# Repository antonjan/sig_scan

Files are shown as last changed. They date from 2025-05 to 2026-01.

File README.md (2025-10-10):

# sig_scan
This project will scan for rf signals and report them if there is signals detected using an rtl-sdr dongle on a a Raspberry Pi<br>
Libraery with exsyended frequency is avalable here https://github.com/librtlsdr/librtlsdr/tree/development<br>
## Pre Req libraeriies
    sudo apt-get install build-essential cmake git
    sudo apt-get install libusb-dev libusb-1.0-0-dev
    git clone https://github.com/librtlsdr/librtlsdr/tree/development
    cd librtlsdr
    git checkout development
    git status

    mkdir build && cd build
    cmake ../ -DINSTALL_UDEV_RULES=ON
    make

    sudo make install
    sudo ldconfig
# Setting up python 
    cd Documents/SX126X_LoRa_HAT_Code/raspberrypi/python/
## Sender 
    source ~/sdr-env/bin/activate
## Receiver
    source venv/bin/activate
# Running SIG Scanner
python gsm_scanner_new2.py

# Rafial R828D pin conections

    R828D (R820T-compatible) Pinout: Pin Number to Name

The R828D is usually supplied in a 32-pin QFN package. Here’s the most commonly reported pinout:

        Pin	Name	Function
        1	VCC	Power supply
        2	VCO	PLL VCO
        3	VCOIN	PLL VCO input
        4	VCOGND	PLL VCO ground
        5	VCOBUF	PLL VCO buffer output
        6	XIN	Crystal oscillator input
        7	XOUT	Crystal oscillator out
        8	VCC	Power supply
        9	GND	Ground
        10	AGC	Automatic Gain Control
        11	IFOUT	Intermediate Frequency Output
        12	VCC	Power supply
        13	GND	Ground
        14	RF_IN	RF Input (from antenna)
        15	GND	Ground
        16	NC	Not Connected
        17	VCC	Power supply
        18	NC	Not Connected
        19	LNA	Low Noise Amp control
        20	VCC	Power supply
        21	GND	Ground
        22	NC	Not Connected
        23	SDA	I²C Data
        24	SCL	I²C Clock
        25	GND	Ground
        26	VCC	Power supply
        27	NC	Not Connected
        28	VCC	Power supply
        29	NC	Not Connected
        30	NC	Not Connected
        31	NC	Not Connected
        32	NC	Not Connected
        30	NC	Not Connected
        31	NC	Not Connected
        32	NC	Not Connected
## Basic Connections

    Antenna → Matching Network → Pin 14 (RF_IN)
    Pin 11 (IFOUT) → RTL2832U IF Input
    Pin 23 (SDA) & Pin 24 (SCL) → RTL2832U I²C (for control)
    Pin 6 (XIN) & Pin 7 (XOUT) → 16 MHz Crystal (one end to XIN, other to XOUT, with load capacitors to GND)
    All VCC Pins → 3.3V Power
    All GND Pins → Ground Plane

## Register Map (Community Reference, RTL-SDR Driver)

The R828D is controlled via I²C. The register map is not openly published, but the rtl-sdr driver configures it as follows:

    I²C Address: 0x8C (write), 0x8D (read)
    Registers:
        Reg 0x00: Tuner enable, AGC, LNA setting
        Reg 0x01–0x05: PLL and frequency control
        Reg 0x06–0x0D: IF settings, filter bandwidth, gain stages
        Reg 0x0E–0x1F: Misc control, calibration, test modes

Example I²C Write Sequence for Initialization:
    
    uint8_t init_regs[] = {
    0x01, 0x16, 0xE0, 0x60, 0x40, // PLL settings
    0x20, 0x80, 0x40,             // IF gain, filter
    0xA1, 0x4B, 0x10              // AGC, LNA, etc.
    };
    i2c_write(R828D_ADDR, init_regs, sizeof(init_regs));
The actual values depend on frequency, IF, and gain requirements.
Refer to rtl-sdr tuner_r820t.c for full register programming examples. https://github.com/osmocom/rtl-sdr/blob/master/src/tuner_r820t.c

Step-by-Step Build Guide

    Connect RF_IN (Pin 14) to antenna/matching network.
    Connect IFOUT (Pin 11) to RTL2832U IF Input.
    Connect SDA (Pin 23) and SCL (Pin 24) to RTL2832U I²C bus. Use pull-up resistors (~4.7kΩ) to 3.3V.
    Connect 16 MHz crystal between XIN (Pin 6) and XOUT (Pin 7), with recommended load capacitors (~22pF) to ground.
    Connect all VCC pins to regulated 3.3V supply.
    Connect all GND pins to system ground.
    AGC (Pin 10) and LNA (Pin 19) can be controlled by RTL2832U or tied appropriately.
    Initialize R828D via I²C using register sequences from open-source drivers.
# R828 c driver 
https://github.com/osmocom/rtl-sdr/blob/master/src/tuner_r82xx.c

    Pin 10 (AGC) → RTL2832U AGC Output (optional, for gain control)
    Pin 19 (LNA) → Can be tied HIGH or controlled by RTL2832U for LNA operation

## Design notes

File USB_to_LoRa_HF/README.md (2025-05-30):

# USB to LoRa HF

The USB-TO-LoRa-xF is a wireless data transfer unit with USB interfaces based on the SX1262 module. Adopts LoRa Modulate and Demodulate technology, with the advantages of anti-interference and long-distance communication (up to 5KM). Supports point-to-point, point-to-multipoint, relay network, AES, etc. Compact size and easy to install.

## How to Restore from Brick

1. Use the Firmware update software on a Windows machine.
2. Put the device into firmware update mode by holding down the KEY button within 3 seconds of powering the device on. The TXD and RXD LED's will flash to show you are in the correct mode.
3. Open the Update software, select the correct COM port and press 'Open COM'.
4. Press on 'Open File' and choose the latest firmware for the corresponding model, such as USB-TO-LoRa-HF-V12.ws, and click the 'Update' button to update.

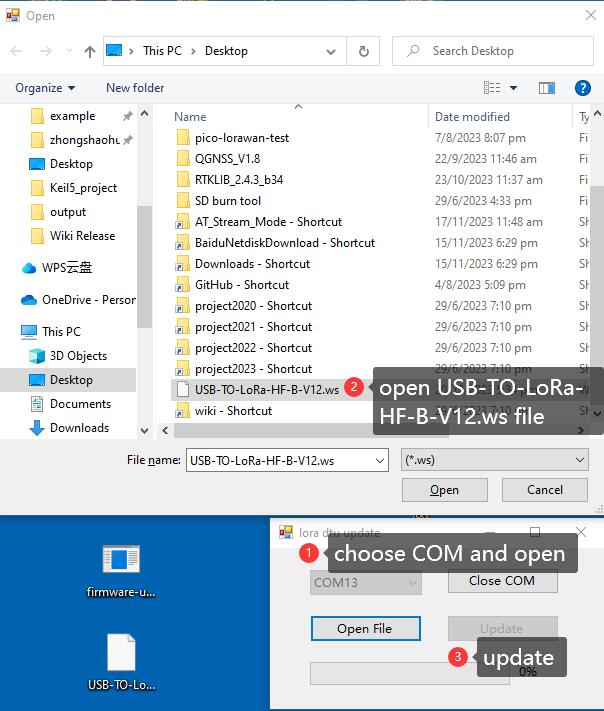
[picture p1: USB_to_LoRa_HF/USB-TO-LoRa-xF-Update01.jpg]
Update01


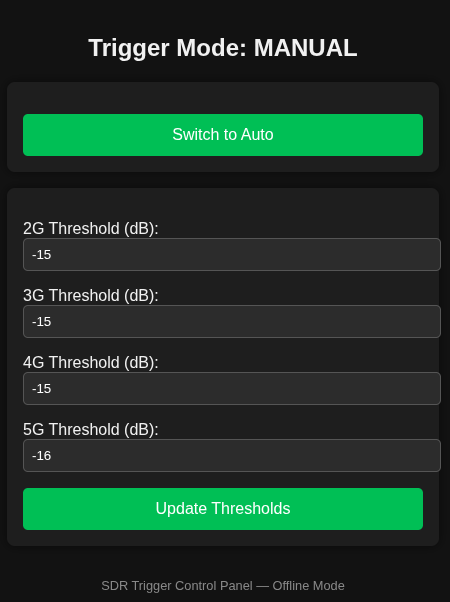
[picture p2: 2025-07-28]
LoRa_Sender_WebServer.png

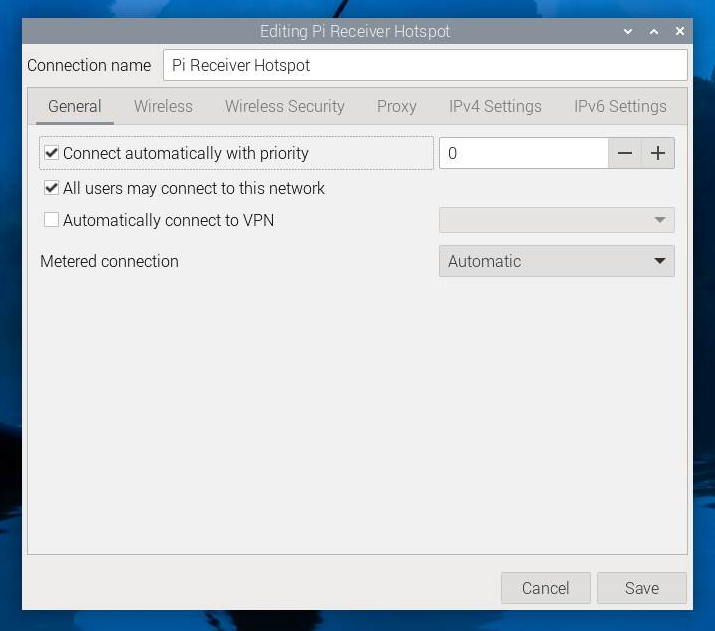
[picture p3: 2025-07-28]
LoRa_Base_Hotspot_Priority.png

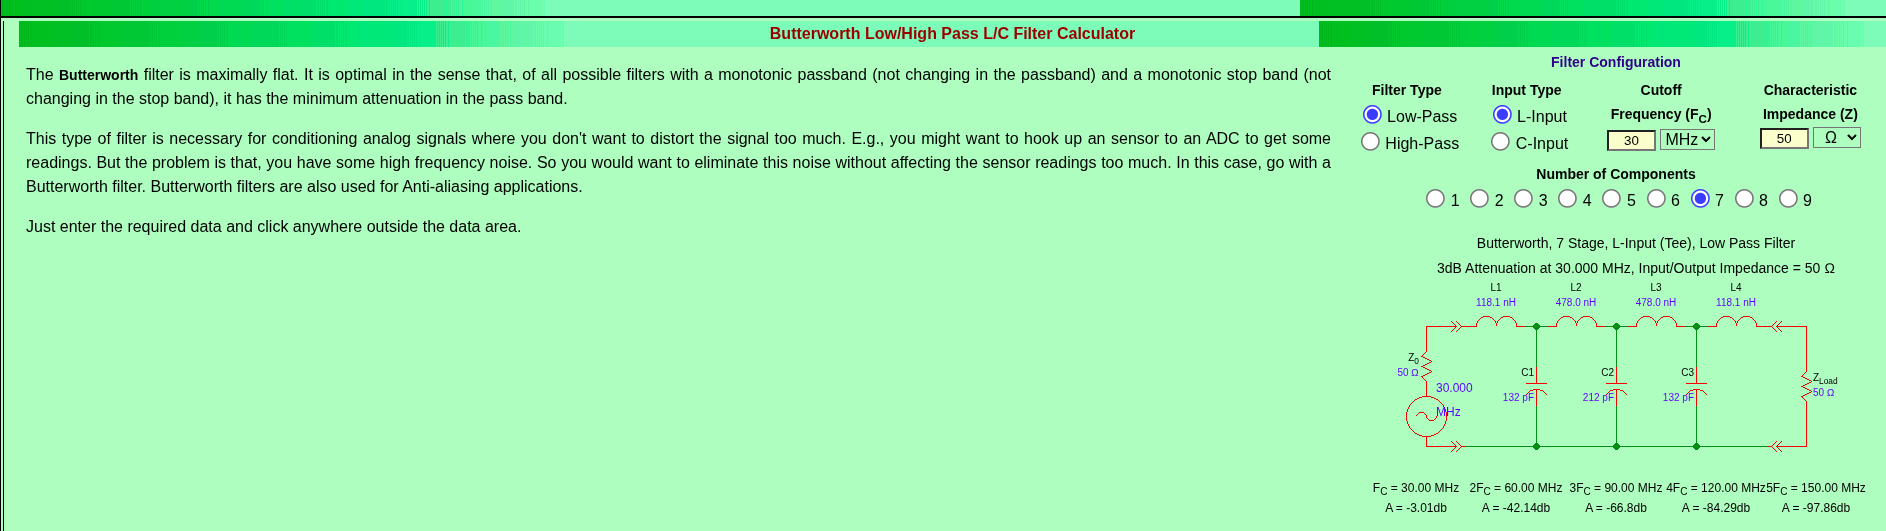
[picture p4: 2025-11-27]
sig_scan_pcb/ButterWorth_30MHz_LPF.png

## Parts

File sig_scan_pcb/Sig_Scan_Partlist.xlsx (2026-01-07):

Id | Designator | Footprint | Quantity | Designation | Mouser
1 | C15,C24 | C_0805_2012Metric | 2 | 132nF | CC0805KRX7R9BB124
2 | C16,C14 | C_0805_2012Metric | 2 | 22uF | CL21A226MAYNNNE
3 | C19 | C_0805_2012Metric | 1 | 27pF | C0805C270K5HACTU
4 | C20 | C_0805_2012Metric | 1 | 212nF | CL21B224KAFNNNE
5 | C23,C22 | C_0805_2012Metric | 2 | 47pF | CC0805JRNPO9BN470
6 | C28,C27,C25 | C_0805_2012Metric | 3 | 10pF | CL21C100CBANNNC
7 | C29,C30 | C_0805_2012Metric | 2 | 39pF | CC0805JRNPO9BN390
8 | C4 | C_0805_2012Metric | 1 | 330pF | C0805C331J5GACTU
9 | C41,C52,C3 | C_0805_2012Metric | 3 | 10nF | 80-C0805C103K5R
10 | C42,C59,C50,C8,C7,C63,C34 | C_0805_2012Metric | 7 | 10uF | 187-CL21A106KOQNNNG
11 | C47,C43,C40,C26,C10,C1,C18 | C_0805_2012Metric | 7 | 1uF | 187-CL21B105KBFNNNE
12 | C49,C48,C46,C45,C44,C21,C64,C55,C51,C37,C35,C60,C56,C61,C2,C36,C11,C9,C57,C32,C39,C5,C12,C31,C38 | C_0805_2012Metric | 25 | 100nF | 603-CC805KRX7R9BB104
13 | C58,C54,C53 | C_0805_2012Metric | 3 | 1.5pF | 603-CC805CRNPO9BN1R5
14 | C6 | C_0805_2012Metric | 1 | 6n8F | CC0805KRX7R9BB682
15 | C62,C33 | C_0805_2012Metric | 2 | 2.2uF | CL21B225KPFNNNE
16 | D1,D2 | D_SOD-123 | 2 | 1N4148W | 637-1N4148W
17 | FB1,FB2 | C_0805_2012Metric | 2 | 600 Ohm Bead | MPZ2012S601AT000
18 | IC1 | SOT230P700X180-4N | 1 | AZ1117H-3.3TRE1 | 621-AZ1117H-3.3TRE1
19 | J1,J4 | SMA_Amphenol_132289_EdgeMount | 2 | Conn_Coaxial
20 | J10,J7 | PinHeader_1x02_P2.54mm_Vertical | 2 | LED Connector | 737-PH1-02-UA
21 | J11,J12 | PinHeader_1x02_P2.54mm_Vertical | 2 | USB Jumper | 737-PH1-02-UA
22 | J13 | PinHeader_1x04_P2.54mm_Vertical | 1 | PROG | 737-PH1-04-UA
23 | J2 | CUI_TB007-508-02BE | 1 | 12V Connector | 490-TB007-508-02BE
24 | J3 | PinHeader_2x15_P2.54mm_Vertical | 1 | GPIO Connector | 649-1012938190802BLF
25 | J5 | USB_C_Receptacle_G-Switch_GT-USB-7010ASV | 1 | UJ20-C-H-G-SMT-P16-TR | 523-12402012E212A
26 | J6 | PinHeader_1x03_P2.54mm_Vertical | 1 | USB Switch | 538-22-28-5032
27 | J8 | PinHeader_1x01_P2.54mm_Vertical | 2 | CLK TP | 737-PH1-07-UA
28 | J9 | PinHeader_1x04_P2.54mm_Vertical | 1 | Conn | 737-PH1-04-UA
29 | L1,L4 | L_1210_3225Metric | 2 | 1mH | NLFV32T-102K-EF
30 | L10 | L_0805_2012Metric | 1 | 10uH | MCL2012V1-100-R
31 | L11 | L_0805_2012Metric | 1 | 2nH | 279-36550603S2N0T
32 | L13,L12 | L_0805_2012Metric | 2 | 2.7nH | 815-AIMC-0805-2N7ST
33 | L3,L2 | L_0805_2012Metric | 2 | 150nH | AIML-0805-R15K-T
34 | L5,L8 | L_0805_2012Metric | 2 | 118.1nH | AIMC-0805-R12J-T
35 | L6,L7 | L_0805_2012Metric | 2 | 478nH | MCL2012V2-471-R
36 | L9 | L_0805_2012Metric | 1 | 24nH | 279-36502A24NJTDG
37 | R1 | R_0805_2012Metric | 1 | 1K8 | RMCF0805JT1K80
38 | R11 | R_0805_2012Metric | 1 | 1K | 603-RT0805DRD071KL
39 | R19,R14,R2,R13 | R_0805_2012Metric | 4 | 10K | 660-RN73R2ATD1002D25
40 | R20 | R_0805_2012Metric | 1 | 6K8 | 754-RG2012P-682-BT5
41 | R21 | R_0805_2012Metric | 1 | 0 Ohm | 594-MCU0805MZ0000ZP5
42 | R22 | R_0805_2012Metric | 1 | 499 | 603-RT0805FRD07499RL
43 | R23,R10,R9,R7,R8,R12 | R_0805_2012Metric | 6 | 220 | 667-ERA-6AEB221V
44 | R25 | R_0805_2012Metric | 1 | 10k | 660-RN73R2ATD1002D25
45 | R26,R24,R18,R16,R17,R15 | R_0805_2012Metric | 6 | 4K7 | 754-RG2012P-472DT5
46 | R3,R6 | R_0805_2012Metric | 2 | 5K1 | 754-RR1220P-512D
47 | R4,R5 | R_0805_2012Metric | 2 | 0 | 594-MCU0805MZ0000ZP5
48 | SW1 | SW_Tactile_SPST_NO_Straight_CK_PTS636Sx25SMTRLFS | 1 | BOOT | 774-222BMVBAR
49 | SW2 | SW_Tactile_SPST_NO_Straight_CK_PTS636Sx25SMTRLFS | 1 | RESET | 774-222BMVBAR
50 | T1 | TCM1382WX | 1 | TCM1-382WX+ | TCM1-382WX+
51 | U1,U4 | SOT-23_DIO | 2 | BAV99-7-F | BAV99-7-F
52 | U2 | SOT230P700X180-4N | 1 | AZ1117H-5.0TRE1 | AZ1117H-5.0TRE1
53 | U3 | QFN50P400X400X90-25N | 1 | R820T
54 | U5 | QFN-56-1EP_7x7mm_P0.4mm_EP4x4mm | 1 | ESP32-S3FN8 | 356-ESP32-S3FN8
55 | U6 | QFN40P600X600X100-49N | 1 | RTL2832U
56 | U7 | SOIC-8_3.9x4.9mm_P1.27mm | 1 | M24C02-WMN | M24C02-WMN6TP
57 | U8 | MODULE_RA-02_LORA | 1 | RA-02_LORA
58 | Y1 | Crystal_SMD_HC49-SD_HandSoldering | 1 | 28.8Mhz | LFXTAL028168
59 | Y2 | ABM810000MHZ12D2W | 1 | 40MHz | 815-M840000MHZ10B1UT
60

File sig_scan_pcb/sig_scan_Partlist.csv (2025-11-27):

Id | Designator | Footprint | Quantity | Designation | Supplier and ref
1 | C14,C22 | C_0805_2012Metric | 2 | 132nF | 603-CC805KRX7R9BB124 | https://www.mouser.co.za/ProductDetail/YAGEO/CC0805KRX7R9BB124?qs=7s%252B3O6pAiyD9ZHoo5oLV4Q%3D%3D
2 | C15,C11 | C_0805_2012Metric | 2 | 22uF | 187-CL21A226MAYNNNE | https://www.mouser.co.za/ProductDetail/Samsung-Electro-Mechanics/CL21A226MAYNNNE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
3 | C16 | C_1206_3216Metric | 1 | 47uF | 80-C1206C476M8PAC | https://www.mouser.co.za/ProductDetail/KEMET/C1206C476M8PAC?qs=lBBRTESop8x77yDs98LYuw%3D%3D
4 | C19 | C_0805_2012Metric | 1 | 212nF | 187-CL21B224KBFNNNF | https://www.mouser.co.za/ProductDetail/Samsung-Electro-Mechanics/CL21B224KBFNNNF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
5 | C21 | C_0805_2012Metric | 1 | 27pF | 791-0805N270J631CT | https://www.mouser.co.za/ProductDetail/Walsin/0805N270J631CT?qs=ZrPdAQfJ6DNZwj%252BbNo9hhw%3D%3D
6 | C24,C40,C67,C78,C64,C70,C1,C47,C74,C43,C18 | C_0805_2012Metric | 11 | 1uF | 187-CL21B105KBFNNNE | https://www.mouser.co.za/ProductDetail/Samsung-Electro-Mechanics/CL21B105KBFNNNE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
7 | C28,C23,C27 | C_0805_2012Metric | 3 | 10pF | 80-C0805C100K5G | https://www.mouser.co.za/ProductDetail/KEMET/C0805C100K5GACTU?qs=3SD0MEbi8oiSMc603vV8xA%3D%3D
8 | C29,C30 | C_0805_2012Metric | 2 | 39pF | 791-0805N390J631CT | https://www.mouser.co.za/ProductDetail/Walsin/0805N390J631CT?qs=ZrPdAQfJ6DPOaaMfCkuovQ%3D%3D
9 | C4 | C_0805_2012Metric | 1 | 330pF | 80-C0805C331J5G | https://www.mouser.co.za/ProductDetail/KEMET/C0805C331J5GACTU?qs=XkeKLm6KyJJ%2F9Nbgl%252BN6dw%3D%3D
10 | C41,C52,C3 | C_0805_2012Metric | 3 | 10nF | 80-C0805C103K5R | https://www.mouser.co.za/ProductDetail/KEMET/C0805C103K5RACTU?qs=cw4evkOYbeJ17Si5k%2FymvA%3D%3D
11 | C48,C20,C68,C77,C55,C45,C51,C37,C35,C60,C56,C61,C46,C2,C36,C10,C49,C69,C9,C25,C57,C44,C71,C32,C72,C39,C5,C65,C12,C31,C26,C38 | C_0805_2012Metric | 32 | 100nF | 603-CC805KRX7R9BB104 | https://www.mouser.co.za/ProductDetail/YAGEO/CC0805KRX7R9BB104?qs=vTakOoo5QyLx0lXWgVtRhQ%3D%3D
12 | C53,C58,C54 | C_0805_2012Metric | 3 | 1.5pF | 603-CC805CRNPO9BN1R5 | https://www.mouser.co.za/ProductDetail/YAGEO/CC0805CRNPO9BN1R5?qs=5q%252BqlK8CmJTspn63PdnbIg%3D%3D
13 | C59,C50,C8,C42,C7,C66,C34,C75,C73 | C_0805_2012Metric | 9 | 10uF | 187-CL21A106KOQNNNG | https://www.mouser.co.za/ProductDetail/Samsung-Electro-Mechanics/CL21A106KOQNNNG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
14 | C6 | C_0805_2012Metric | 1 | 6n8F | 791-0805B682K500CT | https://www.mouser.co.za/ProductDetail/Walsin/0805B682K500CT?qs=fIkAfuXiAQJnCz6rzinLjw%3D%3D
15 | C62,C33 | C_0805_2012Metric | 2 | 2.2uF | 187-CL21B225KOFNNNG | https://www.mouser.co.za/ProductDetail/Samsung-Electro-Mechanics/CL21B225KOFNNNG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
16 | C76,C63 | C_0805_2012Metric | 2 | 22pF | 80-C0805C220K5HACTU | https://www.mouser.co.za/ProductDetail/KEMET/C0805C220K5HACTU?qs=W0yvOO0ixfEHOdsIsVM%2FuQ%3D%3D
17 | D5,D4 | LED_0805_2012Metric | 2 | 7012X5 | 606-7012X5 | https://www.mouser.co.za/ProductDetail/VCC/7012X5?qs=I7nE1oQSFs%252BQVyGrVFfDjQ%3D%3D
18 | D6,D3 | D_SMA | 2 | VSSAF5M6HM3/H | 78-VSSAF5M6HM3/H | https://www.mouser.co.za/ProductDetail/Vishay-General-Semiconductor/VSSAF5M6HM3-H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
19 | D7,D1,D2 | D_SOD-123 | 3 | MBR230LSFT1G | 863-MBR230LSFT1G | https://www.mouser.co.za/ProductDetail/onsemi/MBR230LSFT1G?qs=Jh7l0IbPjid1ZBeNXVj%2FnA%3D%3D
20 | FB1,FB2 | C_0805_2012Metric | 2 | Bead | 810-MPZ2012S601AT000 | https://www.mouser.co.za/ProductDetail/TDK/MPZ2012S601AT000?qs=8Kz9Wu9QwqXtNFDW9LJXAQ%3D%3D
21 | IC1 | SOT230P700X180-4N | 1 | AZ1117H-3.3TRE1 | 621-AZ1117H-3.3TRE1 | https://www.mouser.co.za/ProductDetail/Diodes-Incorporated/AZ1117H-3.3TRE1?qs=FKu9oBikfSkGfSKJazTNfQ%3D%3D
22 | IC2 | QFN50P350X350X100-17N-D | 1 | BQ24650RVAR | 595-BQ24650RVAR | https://www.mouser.co.za/ProductDetail/Texas-Instruments/BQ24650RVAR?qs=0zjllh%252Bnl7YoFsOK3aOUFA%3D%3D
23 | J10 | PinHeader_1x04_P2.54mm_Vertical | 1 | PROG | 737-PH1-04-UA | https://www.mouser.co.za/ProductDetail/Adam-Tech/PH1-04-UA?qs=HoCaDK9Nz5fnp3pp8iwrSQ%3D%3D
24 | J11 | CUI_TB007-508-02BE | 1 | Solar connector | 737-EBQA-02-D-C | https://www.mouser.co.za/ProductDetail/Adam-Tech/EBQA-02-D-C?qs=HoCaDK9Nz5c3DTE7K1fmdQ%3D%3D
25 | J12 | PinHeader_1x03_P2.54mm_Vertical | 1 | TS Conn | 538-22-28-5032 | https://www.mouser.co.za/ProductDetail/Molex/22-28-5032?qs=PsBcBlklIFWhBc9FIlgSpQ%3D%3D
26 | J14 | CUI_TB007-508-02BE | 1 | BAT connector | 737-EBPA-02-D-C | https://www.mouser.co.za/ProductDetail/Adam-Tech/EBPA-02-D-C?qs=HoCaDK9Nz5c93PCtj8Z8%252BQ%3D%3D
27 | J2 | CUI_TB007-508-02BE | 1 | 12V Connector | 737-EBQA-02-D-C | https://www.mouser.co.za/ProductDetail/Adam-Tech/EBQA-02-D-C?qs=HoCaDK9Nz5c3DTE7K1fmdQ%3D%3D
28 | J4 | USB_C_Receptacle_G-Switch_GT-USB-7010ASV | 1 | UJ20-C-H-G-SMT-P16-TR | 523-12402012E212A | https://www.mouser.co.za/ProductDetail/Amphenol-Commercial-Products/12402012E212A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
29 | J5 | PinHeader_1x03_P2.54mm_Vertical | 1 | USB Switch | 538-22-28-5032 | https://www.mouser.co.za/ProductDetail/Molex/22-28-5032?qs=PsBcBlklIFWhBc9FIlgSpQ%3D%3D
30 | J6,J9 | PinHeader_1x02_P2.54mm_Vertical | 2 | LED Connector | 737-PH1-02-UA | https://www.mouser.co.za/ProductDetail/Adam-Tech/PH1-02-UA?qs=HoCaDK9Nz5dVT5LAE%2F6mlA%3D%3D
31 | J7 | PinHeader_1x01_P2.54mm_Vertical | 1 | CLK TP
32 | J8 | PinHeader_1x04_P2.54mm_Vertical | 1 | Conn | 737-PH1-04-UA | https://www.mouser.co.za/ProductDetail/Adam-Tech/PH1-04-UA?qs=HoCaDK9Nz5fnp3pp8iwrSQ%3D%3D
33 | L1 | L_0805_2012Metric | 1 | 100nH | 504-MCL2012V2-101-R | https://www.mouser.co.za/ProductDetail/Eaton-Electronics/MCL2012V2-101-R?qs=uwxL4vQweFNcRtzbKa8S%2FA%3D%3D
34 | L10 | L_0805_2012Metric | 1 | 24nH | 279-36502A24NJTDG | https://www.mouser.co.za/ProductDetail/TE-Connectivity-Holsworthy/36502A24NJTDG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
35 | L11 | L_0805_2012Metric | 1 | 10uH | 963-LBR2012T100K | https://www.mouser.co.za/ProductDetail/TAIYO-YUDEN/LBR2012T100K?qs=PzICbMaShUet3AhlAozLXg%3D%3D
36 | L12 | L_0603_1608Metric | 1 | 2nH | 279-36550603S2N0T | https://www.mouser.co.za/ProductDetail/TE-Connectivity-Sigma-Inductors/36550603S2N0T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
37 | L14,L13 | L_0805_2012Metric | 2 | 2.7nH | 815-AIMC-0805-2N7ST | https://www.mouser.co.za/ProductDetail/ABRACON/AIMC-0805-2N7S-T?qs=1vO2EIVe%252BY6eZ1oTW4jIxQ%3D%3D
38 | L15,L17 | PIS150H471M | 2 | PIS150H-471M | 871-PIS150H-471M | https://www.mouser.co.za/ProductDetail/EPCOS-TDK/PIS150H-471M?qs=Y0Uzf4wQF3ncdYG5ACt1MQ%3D%3D
39 | L16 | IND_IHLP_2525_CZ_VIS | 1 | 10uH | 70-IHLP2525CZER100M0 | https://www.mouser.co.za/ProductDetail/Vishay-Dale/IHLP2525CZER100M01?qs=PA%252BPfIdQ8xl3JLrMc5InbA%3D%3D
40 | L2 | L_0805_2012Metric | 1 | 8n2H | 70-IMC0805ER6N8J01 | https://www.mouser.co.za/ProductDetail/Vishay-Dale/IMC0805ER6N8J01?qs=XQ00FSfuEDBIwky5dw2f5A%3D%3D
41 | L4,L3 | L_0805_2012Metric | 2 | 150nH | 704-MCQ1V2012-R150-R | https://www.mouser.co.za/ProductDetail/Eaton-Electronics/MCQ1V2012-R150-R?qs=hWgE7mdIu5RRCZO5Km%2FxVA%3D%3D
42 | L5,L9 | L_0603_1608Metric | 2 | 118.1nH | 704-MCQ1V1608-R120-R | https://www.mouser.co.za/ProductDetail/Eaton-Electronics/MCQ1V1608-R120-R?qs=hWgE7mdIu5Qzf3M81zGUgg%3D%3D
43 | L6,L8 | L_0603_1608Metric | 2 | 478nH | 81-LQW18CAR48J00D | https://www.mouser.co.za/ProductDetail/Murata-Electronics/LQW18CAR48J00D?qs=B6kkDfuK7%2FDPLgYzVH3Q7Q%3D%3D
44 | L7 | SRR12604R7Y | 1 | 470uH | 652-SRR1260-4R7Y | https://www.mouser.co.za/ProductDetail/Bourns/SRR1260-4R7Y?qs=meVWcSOgEr6HGQUyq2JiMQ%3D%3D
45 | Q1,Q2 | SOT-23 | 2 | AO3407A | 942-IRLML9301TRPBF | https://www.mouser.co.za/ProductDetail/Infineon-Technologies/IRLML9301TRPBF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
46 | Q3 | TRANS_SI7540DP-T1-GE3 | 1 | SI7540DP-T1-GE3 | 78-SI7540ADP-T1-GE3 | https://www.mouser.co.za/ProductDetail/Vishay-Semiconductors/SI7540ADP-T1-GE3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
47 | R1 | R_0805_2012Metric | 1 | 1K8 | 603-RT0805DRE071K8L | https://www.mouser.co.za/ProductDetail/YAGEO/RT0805DRE071K8L?qs=4CyHz7GXqSgeZuE8NeOh8Q%3D%3D
48 | R10,R9,R7,R8 | R_0805_2012Metric | 4 | 22 | 603-RT0805FRE0722RL | https://www.mouser.co.za/ProductDetail/YAGEO/RT0805FRE0722RL?qs=4CyHz7GXqSjFgtADk71z4w%3D%3D
49 | R11 | R_0805_2012Metric | 1 | 1K | 603-RT0805DRD071KL | https://www.mouser.co.za/ProductDetail/YAGEO/RT0805DRD071KL?qs=%2Ff7pOCXLR5ewqqWXi%2FF%2FCQ%3D%3D
50 | R16,R2,R30,R40,R35,R22,R28,R15 | R_0805_2012Metric | 8 | 10K | 660-RN73R2ATD1002D25 | https://www.mouser.co.za/ProductDetail/KOA-Speer/RN73R2ATTD1002D25?qs=vLWxofP3U2xnxl%252BA6Ay9WA%3D%3D
51 | R18,R37 | R_0805_2012Metric | 2 | 100 | 754-RR1220P-101D | https://www.mouser.co.za/ProductDetail/Susumu/RR1220P-101-D?qs=nCAm%252BcMdy9wY7%252BMDbbfOYA%3D%3D
52 | R19,R27,R20,R21,R17,R29 | R_0805_2012Metric | 6 | 4K7 | 754-RG2012P-472DT5 | https://www.mouser.co.za/ProductDetail/Susumu/RG2012P-472-D-T5?qs=CJ5eSktU8ix1IotnIcwuKA%3D%3D
53 | R23 | R_0805_2012Metric | 1 | 6K8 | 667-ERA-6AED682V | https://www.mouser.co.za/ProductDetail/Panasonic/ERA-6AED682V?qs=MNPzkKEzRtSOnTv2T8P5Xw%3D%3D
54 | R24,R4,R5 | R_0805_2012Metric | 3 | 0 Ohm | 594-MCU0805MZ0000ZP5 | https://www.mouser.co.za/ProductDetail/Vishay-Beyschlag/MCU0805MZ0000ZP500?qs=W0yvOO0ixfGkgjlHiiSC7A%3D%3D
55 | R25 | R_0805_2012Metric | 1 | 499 | 603-RT0805FRD07499RL | https://www.mouser.co.za/ProductDetail/YAGEO/RT0805FRD07499RL?qs=k2KEx2DUIRQtcZ0PJGgLRw%3D%3D
56 | R26,R14,R39,R13 | R_0805_2012Metric | 4 | 220 | 667-ERA-6AEB221V | https://www.mouser.co.za/ProductDetail/Panasonic/ERA-6AEB221V?qs=1VWA5LkbEaoReXXdTz505g%3D%3D
57 | R3,R6 | R_0805_2012Metric | 2 | 5K1 | 754-RR1220P-512D | https://www.mouser.co.za/ProductDetail/Susumu/RR1220P-512-D?qs=U7dmUkNviFvBDekrzeB9Dw%3D%3D
58 | R31,R43 | R_0805_2012Metric | 2 | 499K | 667-ERA-6AEB4993V | https://www.mouser.co.za/ProductDetail/Panasonic/ERA-6AEB4993V?qs=nuXzIS8loXHhUZMt%252BA%252BKHA%3D%3D
59 | R32 | R_0805_2012Metric | 1 | 36K | 603-RT0805FRE0736KL | https://www.mouser.co.za/ProductDetail/YAGEO/RT0805FRE0736KL?qs=4CyHz7GXqSjO0%2F5giFIsGA%3D%3D
60 | R33 | R_0805_2012Metric | 1 | 5K23 | 667-ERA-6AEB5231V | https://www.mouser.co.za/ProductDetail/Panasonic/ERA-6AEB5231V?qs=nuXzIS8loXGCwpaD9zRw7Q%3D%3D
61 | R34 | R_0805_2012Metric | 1 | 30K1 | 603-RT0805DRE0730K1L | https://www.mouser.co.za/ProductDetail/YAGEO/RT0805DRE0730K1L?qs=4CyHz7GXqSh1c76uzoBftg%3D%3D
62 | R36 | R_0805_2012Metric | 1 | 10 | 603-RT0805FRE1310RL | https://www.mouser.co.za/ProductDetail/YAGEO/RT0805FRE1310RL?qs=1mbolxNpo8cxANW8i7GXPg%3D%3D
63 | R41 | R_0805_2012Metric | 1 | 2.2 | 71-TNPW08052R20DEEA | https://www.mouser.co.za/ProductDetail/Vishay/TNPW08052R20DEEA?qs=vHuUswq2%252Bsy8CzTFRktK%252BQ%3D%3D
64 | R42 | R_1206_3216Metric | 1 | 0.033 | 667-ERJ-8BWFR033V | https://www.mouser.co.za/ProductDetail/Panasonic/ERJ-8BWFR033V?qs=KH2o3k57USizqVJBom8vuQ%3D%3D
65 | R44,R12,R38 | R_0805_2012Metric | 3 | 100K | 603-RT0805DRE07100KL | https://www.mouser.co.za/ProductDetail/YAGEO/RT0805DRE07100KL?qs=4CyHz7GXqShqMq5vnkRB7g%3D%3D
66 | SW1 | SW_Tactile_SPST_NO_Straight_CK_PTS636Sx25SMTRLFS | 1 | BOOT | 774-222BMVBAR | https://www.mouser.co.za/ProductDetail/CTS-Electronic-Components/222BMVBAR?qs=%252BiOMRfgENTHtioQvkKc8YQ%3D%3D
67 | SW2 | SW_Tactile_SPST_NO_Straight_CK_PTS636Sx25SMTRLFS | 1 | RESET | 774-222BMVBAR | https://www.mouser.co.za/ProductDetail/CTS-Electronic-Components/222BMVBAR?qs=%252BiOMRfgENTHtioQvkKc8YQ%3D%3D
68 | T1 | TCM1382WX | 1 | TCM1-382WX+ | 139-TCM1-382WX | https://www.mouser.co.za/ProductDetail/Mini-Circuits/TCM1-382WX%2b?qs=amGC7iS6iy9TpOSpP5xMJQ%3D%3D
69 | U1 | SOT-23_DIO | 1 | BAV99-7-F | 621-BAV99-F | https://www.mouser.co.za/ProductDetail/Diodes-Incorporated/BAV99-7-F?qs=E9Ihi8A05%252BSTVRjo74hQDA%3D%3D
70 | U2 | SOT230P700X180-4N | 1 | AZ1117H-5.0TRE1 | AZ1117H-5.0TRE1 | https://www.mouser.co.za/ProductDetail/Diodes-Incorporated/AZ1117H-5.0TRE1?qs=FKu9oBikfSlW5RUAHfdJtw%3D%3D
71 | U3 | QFN50P400X400X90-25N | 1 | R820T (R860)
72 | U4 | QFN-56-1EP_7x7mm_P0.4mm_EP4x4mm | 1 | ESP32-S3FN8 | 356-ESP32-S3FN8 | https://www.mouser.co.za/ProductDetail/Espressif-Systems/ESP32-S3FN8?qs=Rp5uXu7WBW%2F4Oihh5tkiVQ%3D%3D
73 | U5 | QFN40P600X600X100-49N | 1 | RTL2832U
74 | U6 | SOIC-8_3.9x4.9mm_P1.27mm | 1 | M24C02-WMN | 511-M24C02-RMN6TP | https://www.mouser.co.za/ProductDetail/STMicroelectronics/M24C02-RMN6TP?qs=Jodr3Ka7a6ktinv3aZzndw%3D%3D
75 | U7 | MODULE_RA-02_LORA | 1 | RA-02_LORA
76 | Y1 | ATX11F32000MHZF05T | 1 | 28.8MHz
77 | Y2 | ABM810000MHZ12D2W | 1 | 40MHz | 815-M840000MHZ10B1UT | https://www.mouser.co.za/ProductDetail/ABRACON/ABM8-40.000MHZ-10-B1U-T?qs=vLWxofP3U2wkoldm7I3eOw%3D%3D

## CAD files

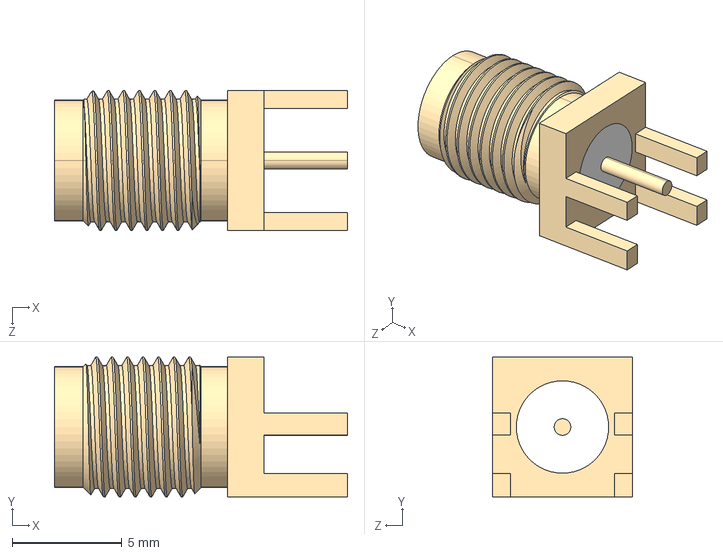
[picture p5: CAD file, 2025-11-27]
sig_scan_pcb/Components/CON_SMA_EDGE_S/CON-SMA-EDGE-S.step
13.3 x 6.35 x 6.35 mm

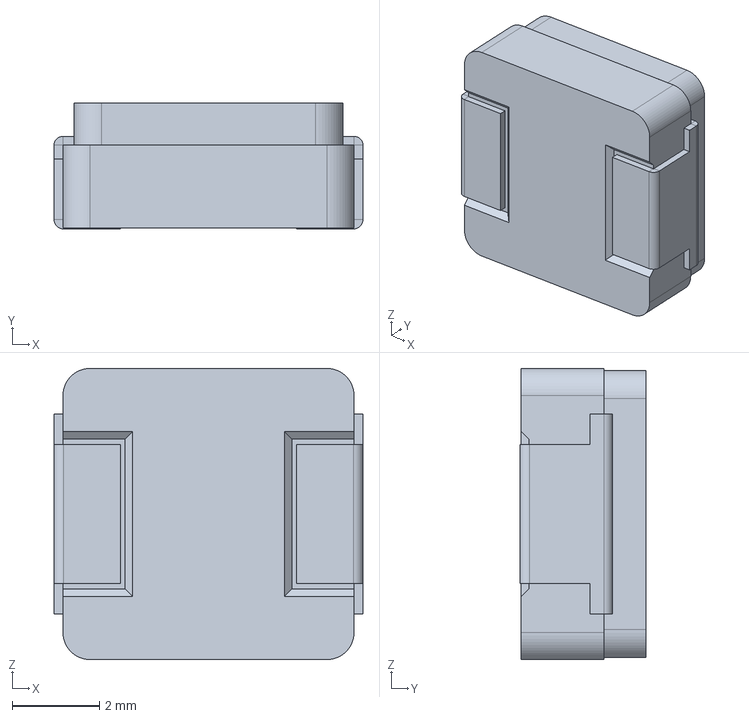
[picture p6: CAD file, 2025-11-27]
sig_scan_pcb/Components/IHLP2525CZER100M01/KiCADv6/IHLP2525CZER100M01/ihlp2525czer100m01.stp
7.08 x 2.88 x 6.67 mm

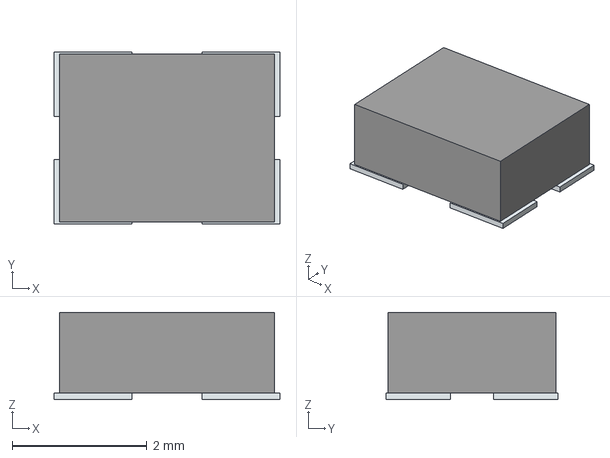
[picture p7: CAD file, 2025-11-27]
sig_scan_pcb/Components/LIB_ATX-11-F-32.000MHZ-F05-T/ATX-11-F-32.000MHZ-F05-T/3D/ATX-11-F-32.000MHZ-F05-T.stp
3.36 x 2.56 x 1.30 mm
Pins

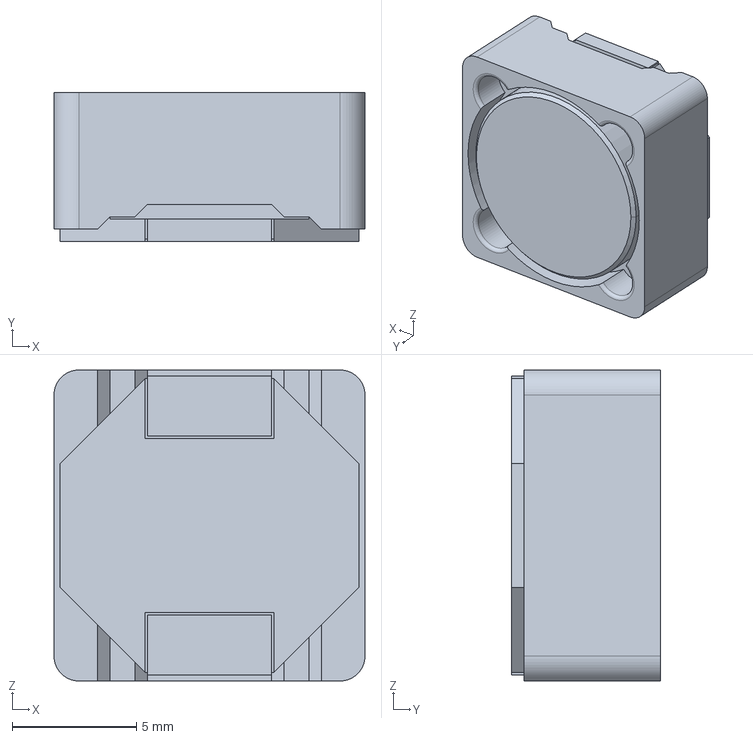
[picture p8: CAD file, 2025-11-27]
sig_scan_pcb/Components/LIB_SRR1260-471K/SRR1260-471K/3D/SRR1260-471K.stp
12.5 x 6.00 x 12.5 mm

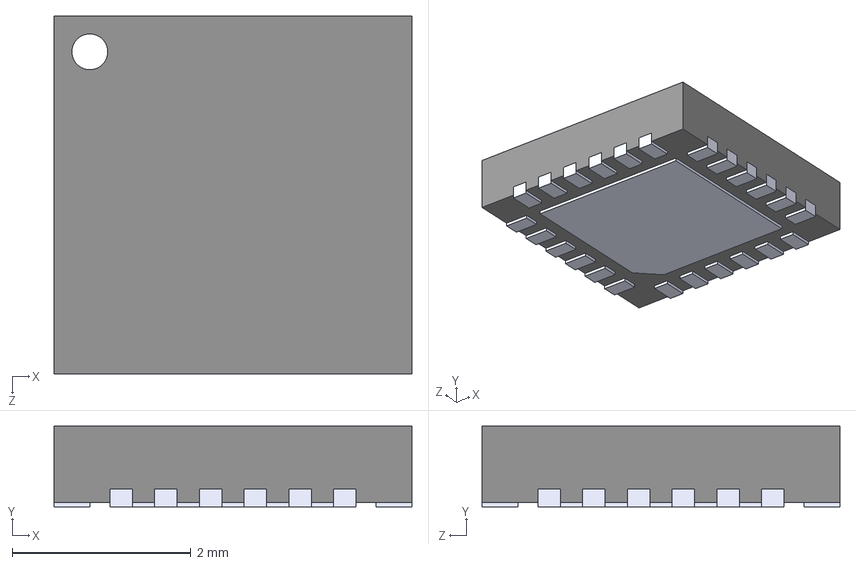
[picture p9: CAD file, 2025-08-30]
sig_scan_pcb/Components/R820T/R820T.step
4.00 x 0.9 x 4.00 mm

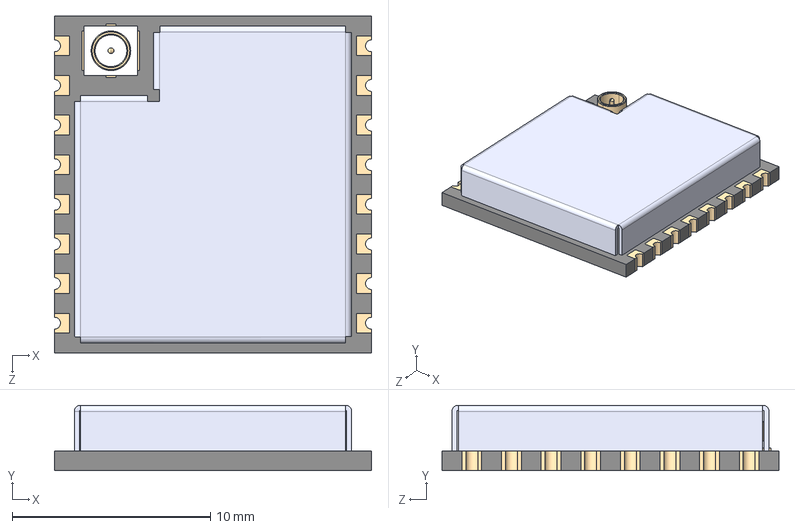
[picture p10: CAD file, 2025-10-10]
sig_scan_pcb/Components/RA-02_LORA/RA-02_LORA.step
16.0 x 3.30 x 17.0 mm

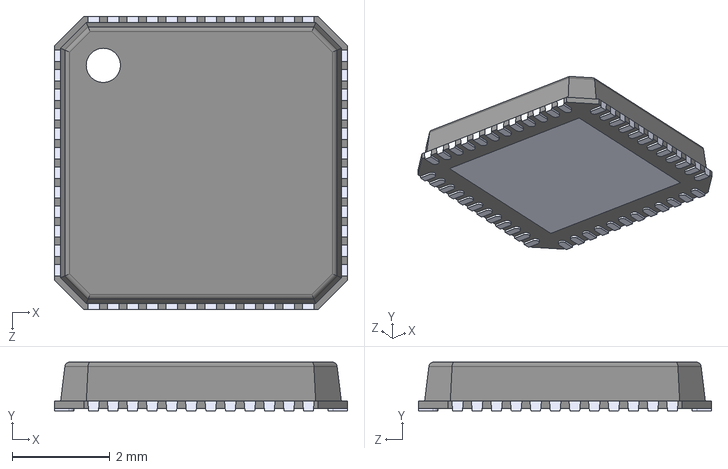
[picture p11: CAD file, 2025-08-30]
sig_scan_pcb/Components/RTL2832U/RTL2832U.step
6.00 x 1.00 x 6.00 mm

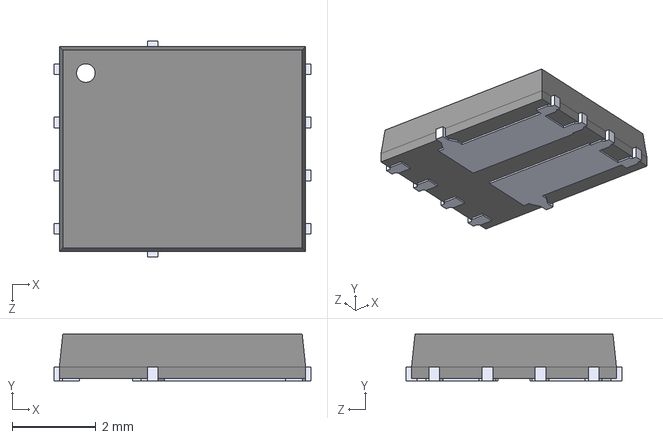
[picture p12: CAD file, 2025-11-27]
sig_scan_pcb/Components/SI7540DP-T1-GE3/SI7540DP-T1-GE3.step
6.15 x 1.12 x 5.16 mm

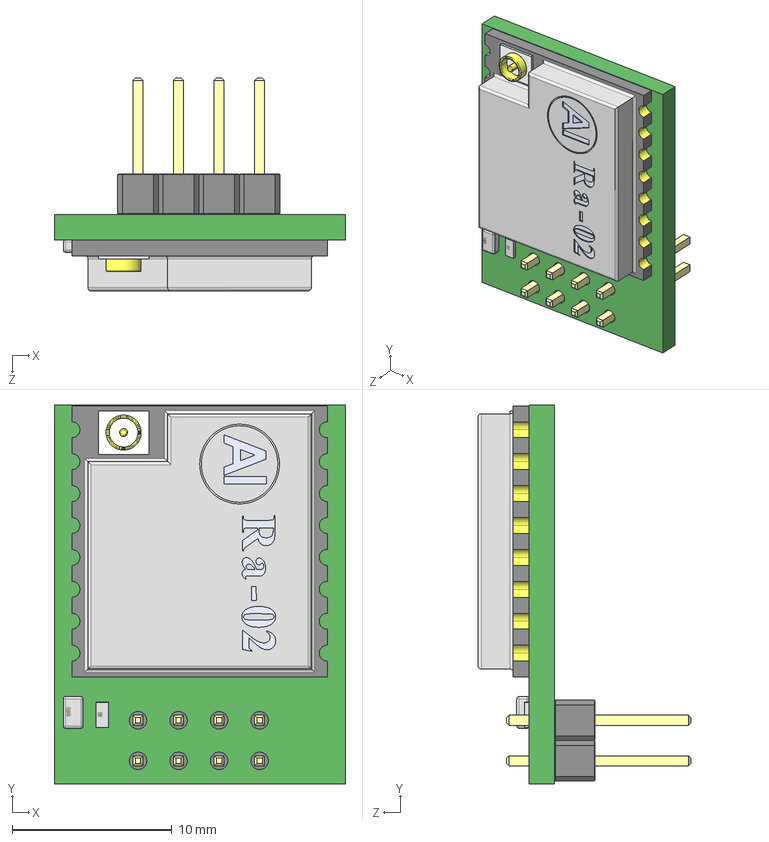
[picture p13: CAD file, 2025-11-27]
sig_scan_pcb/Components/User Library-LoRa Ra-01.STEP
18.2 x 23.8 x 13.3 mm
SW3dPS-0603_SMD_Capacitor
SW3dPS-0805_SMD_Capacitor
прямой_штырь x 10
основание x 10
User_Library-RA-02

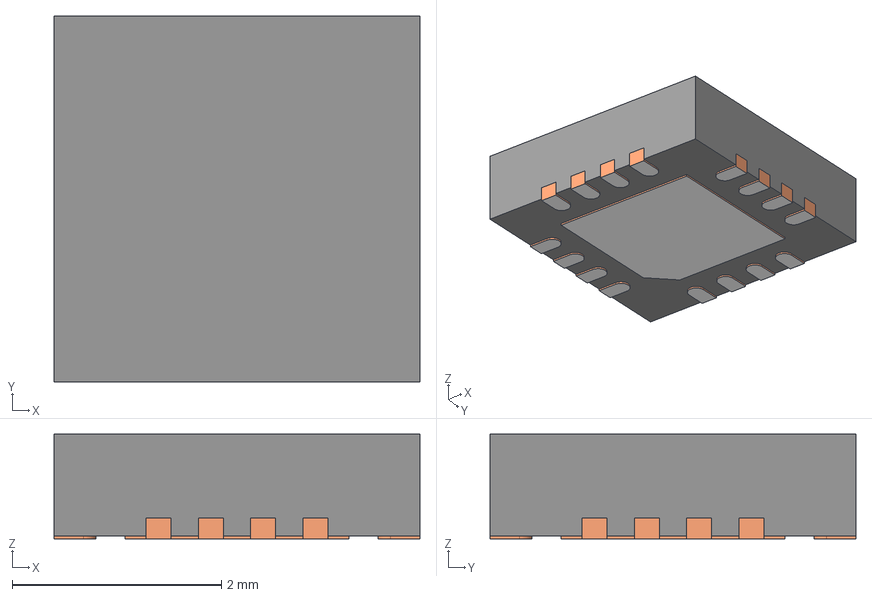
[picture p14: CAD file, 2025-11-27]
sig_scan_pcb/Components/LIB_BQ24650RVAR/BQ24650RVAR/3D/BQ24650RVAR.stp
3.50 x 3.50 x 1.00 mm
BODY-QFN
FRAME-RVA0016A
PIN1-ID

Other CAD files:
sig_scan_pcb/Components/LIB_ATX-11-F-32.000MHZ-F05-T/ATX-11-F-32.000MHZ-F05-T/Allegro/atx11f32000mhzf05t.psm
sig_scan_pcb/Components/LIB_ATX-11-F-32.000MHZ-F05-T/ATX-11-F-32.000MHZ-F05-T/DEHDL/atx_11_f_32.000mhz_f05_t/chips/chips.prt
sig_scan_pcb/Components/LIB_BQ24650RVAR/BQ24650RVAR/Allegro/qfn50p350x350x100-17n-d.psm
sig_scan_pcb/Components/LIB_BQ24650RVAR/BQ24650RVAR/DEHDL/bq24650rvar/chips/chips.prt
sig_scan_pcb/Components/LIB_PIS150H-471M/PIS150H-471M/Allegro/pis150h471m.psm
sig_scan_pcb/Components/LIB_PIS150H-471M/PIS150H-471M/DEHDL/pis150h_471m/chips/chips.prt
sig_scan_pcb/Components/LIB_SRR1260-471K/SRR1260-471K/Allegro/srr12604r7y.psm
sig_scan_pcb/Components/LIB_SRR1260-471K/SRR1260-471K/DEHDL/srr1260_471k/chips/chips.prt
sig_scan_pcb/Components/LIB_TCM1-382WX+/TCM1-382WX+/Allegro/tcm1382wx.psm
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

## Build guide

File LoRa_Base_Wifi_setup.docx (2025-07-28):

# Hotspot Setup for LoRa Receiver

WiFi name: Free Wifi

Password: 2222!2222

once the rasp-pi-lora-base connects to the hotspot check the IP of the Pi.

The IP address may be different based on the hotpsot

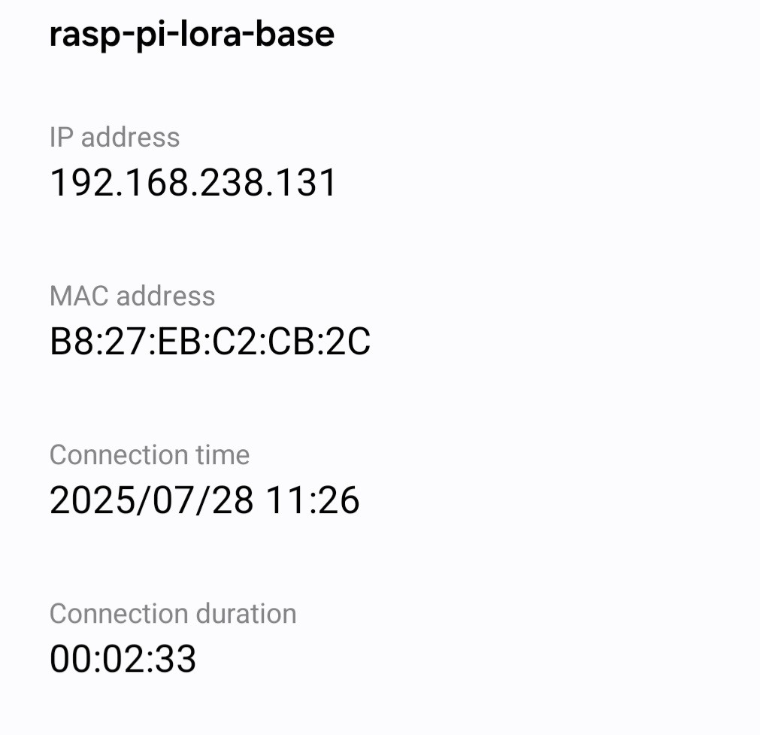
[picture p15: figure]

once you have the IP address while on the same hotspot go to your browser and enter the IP plus :5000 to access the port for example: 192.168.238.131:5000

this should bring up this screen

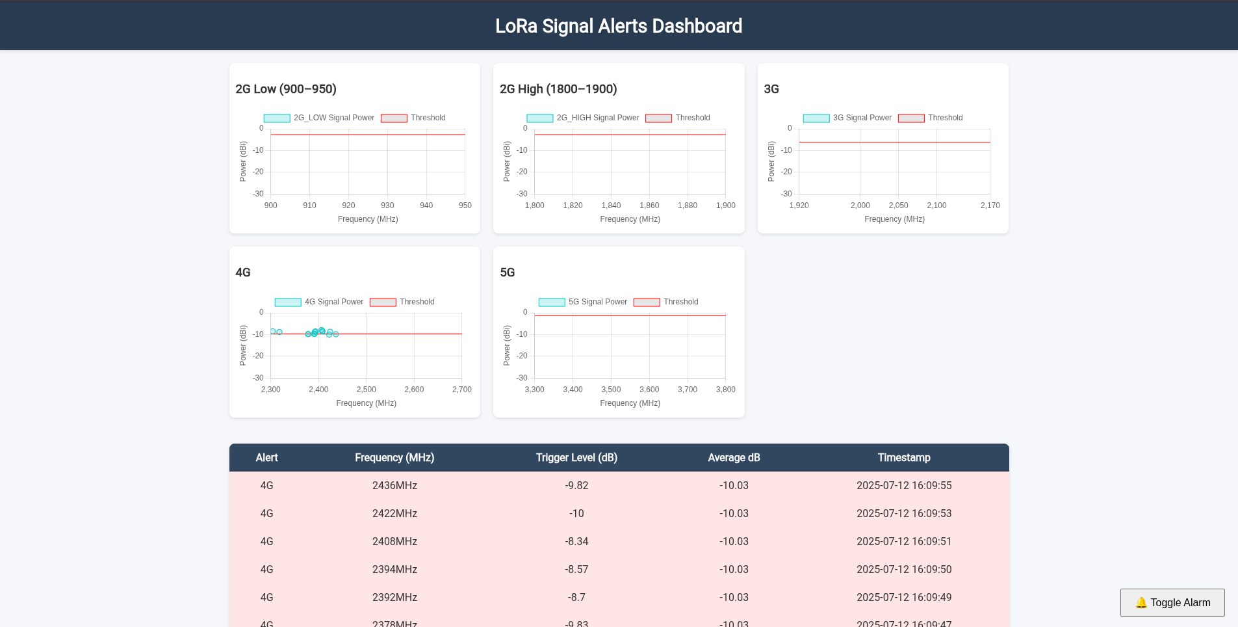
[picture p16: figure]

# How to configure LoRa Receiver WiFi

1. Connect the PI through Ethernet to a WiFi or connect it to a display through the mini HDMI connector on the Pi( if connected to a display skip to step 5).

2. Use any type of VNC software e.g. TigerVNC

3. In TigerVNC connect the Pi’s IP

4. When asked for the Username and Password use pi and zr6aic respectively

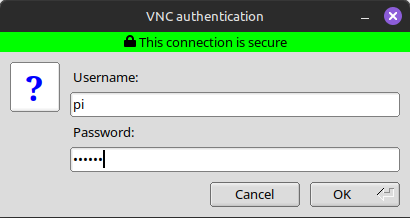
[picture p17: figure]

5. Once the Pi screen appears, go to the WiFi icon on the top right corner. Hover over advanced options and select “Edit Connections”.

6. Once the new screen appears in the bottom left click on the Plus symbol to create a new connection.

7. In the choose type select “Wireless”.

8. In Connection name, enter whatever you want for example My WiFi, then select the General tab.

9. In the General tab make sure “Connect automatically with priority” is selected, then go to the Wireless tab.

10. Once in the Wireless tab enter the WiFi name in the SSID, then go to the Wireless Security tab.

11. Once there in the Security drop down select WPA/WPA2/WPA3 Personal and enter the password for the WiFi in the password section.

12. Once done click on Save to close the window and then click the X in the top right to close the Network Connections.

13. You can now restart the Pi to use the new Wifi connection, it may take some time for the Pi to connect to the WiFi.

# LoRa Sender Web Server

1. Once the Sender Pi has been powered on, after some time it will activate its Hotspot called PiWebServer, connect using the password 12345678. Make sure your device is set to connect even though there is no internet.


2. Once connected go to your Web Browser and type in the IP 10.42.0.1:8080 to access the configuration Webpage.

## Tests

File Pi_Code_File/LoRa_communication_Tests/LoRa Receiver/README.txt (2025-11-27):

In this folder we added the Code for the Transmitter side (SX1262 868M LoRa HAT), the receiver side (USB-TO-LoRa-HF), a diagram PNG of our process and a PNG of GQRX to show that the transmitter is sending.

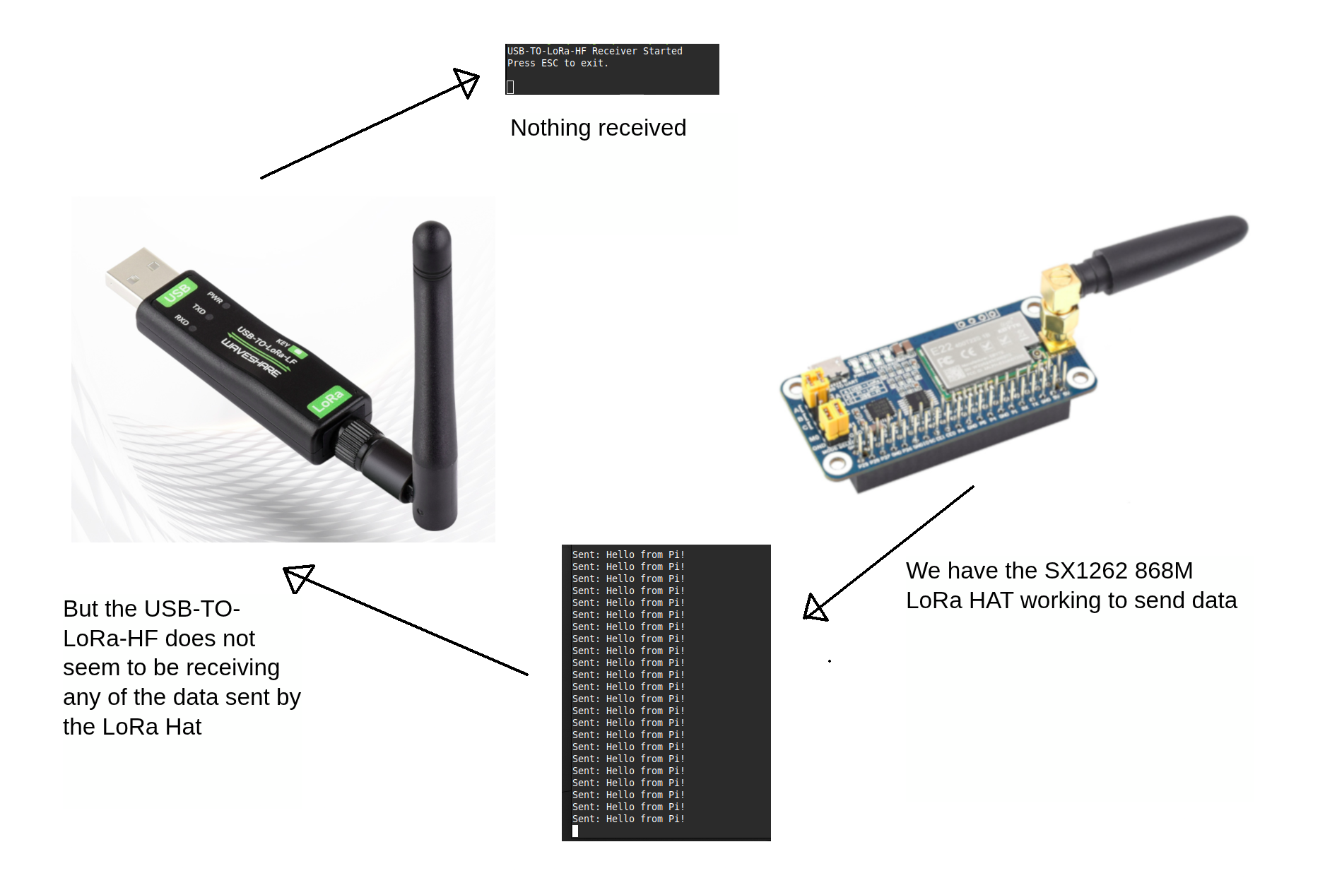
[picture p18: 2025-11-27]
Pi_Code_File/LoRa_communication_Tests/LoRa Receiver/LoRa Receiver.png

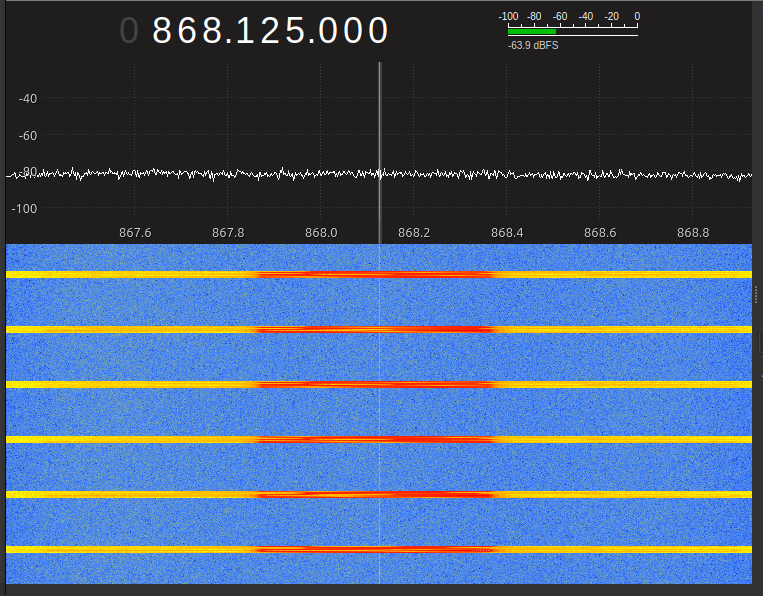
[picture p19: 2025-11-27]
Pi_Code_File/LoRa_communication_Tests/LoRa Receiver/GQRX_Transmitter_Signal.png

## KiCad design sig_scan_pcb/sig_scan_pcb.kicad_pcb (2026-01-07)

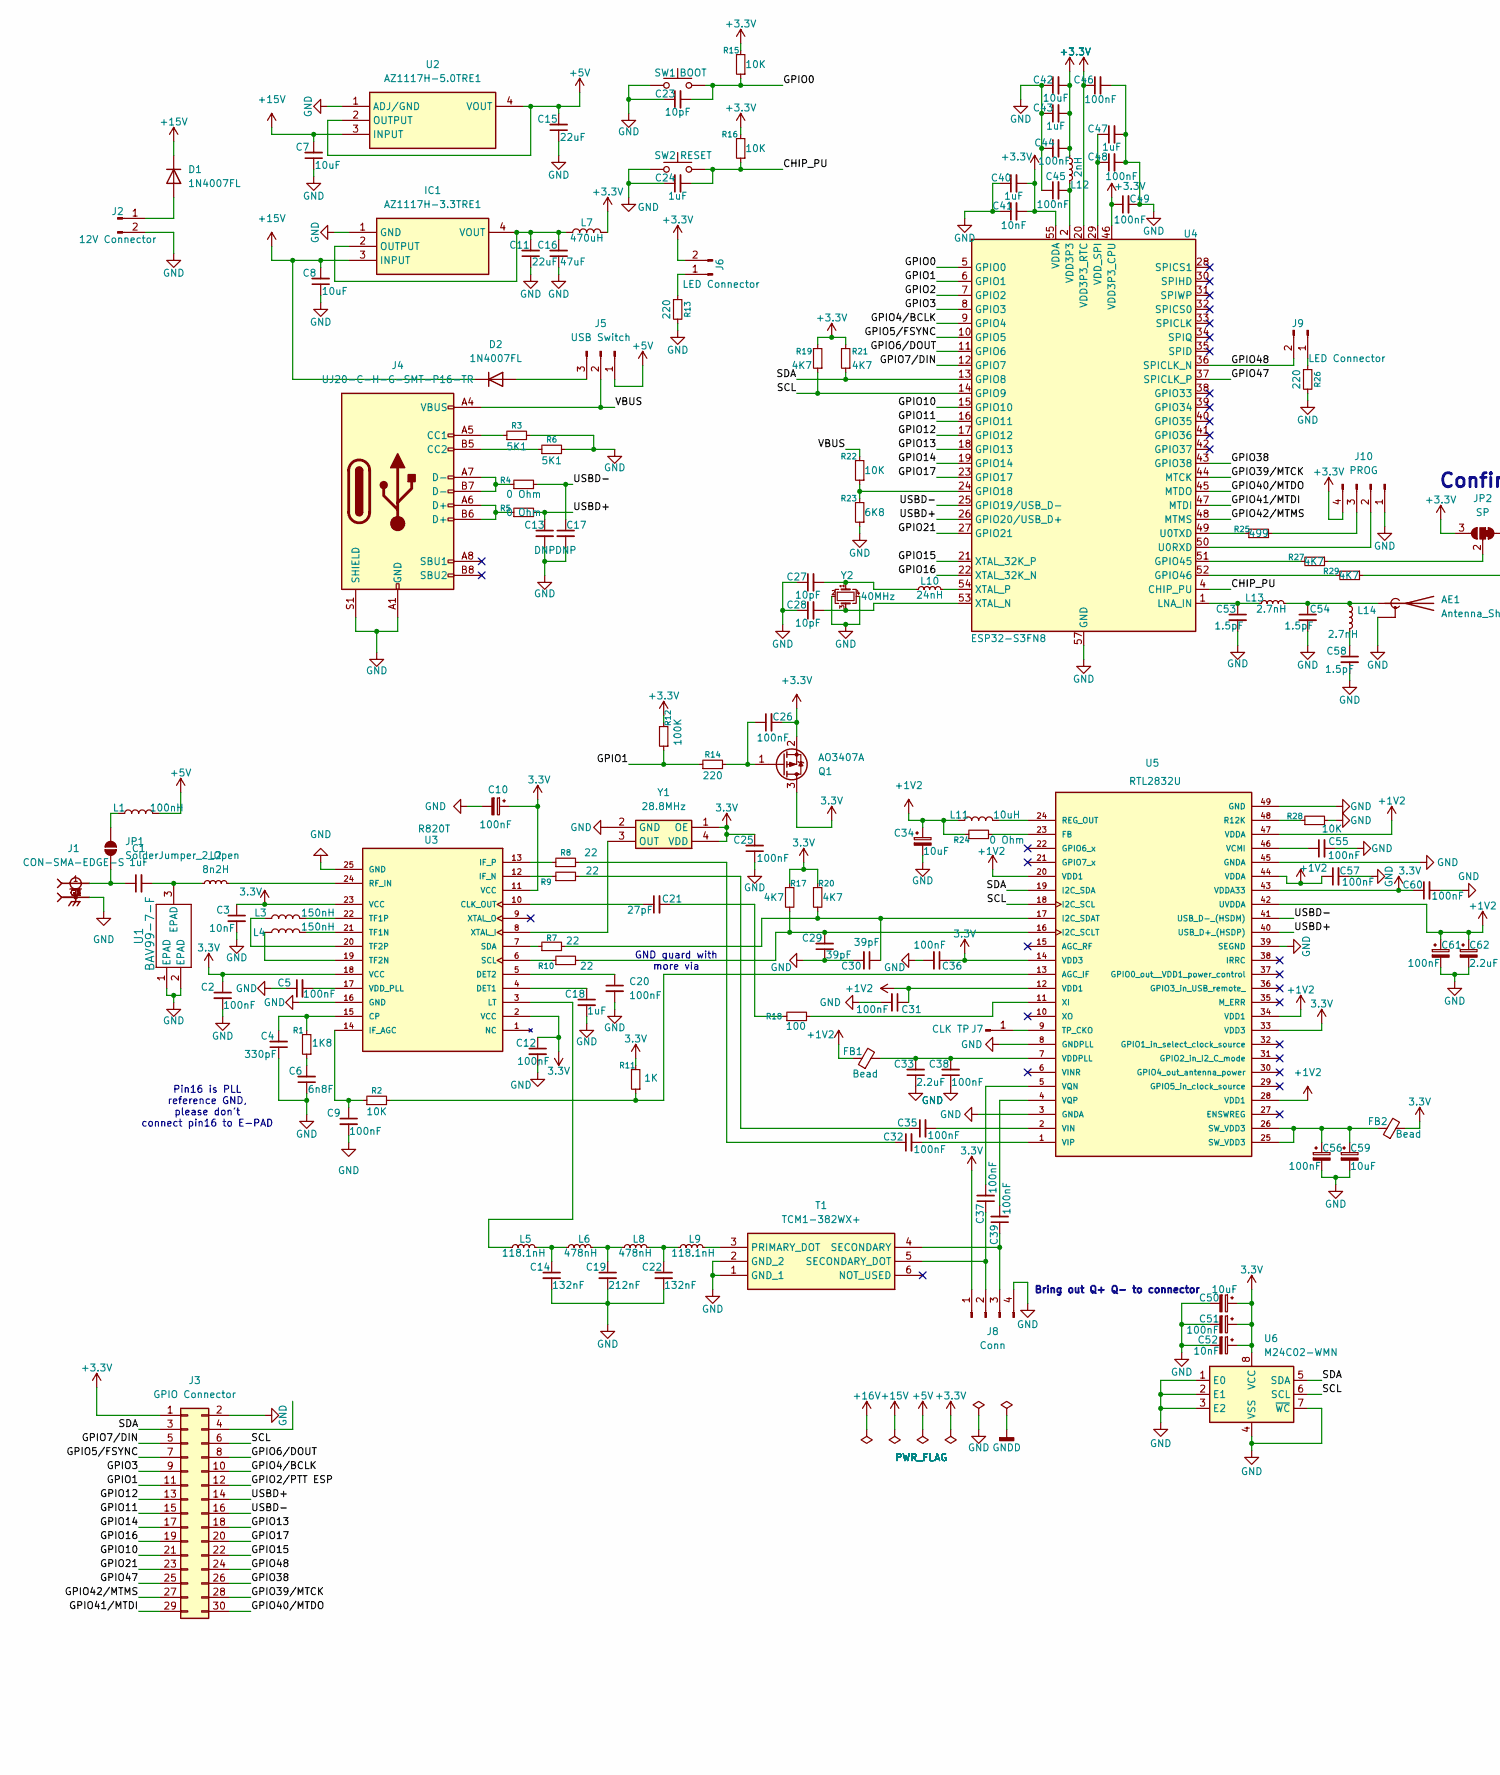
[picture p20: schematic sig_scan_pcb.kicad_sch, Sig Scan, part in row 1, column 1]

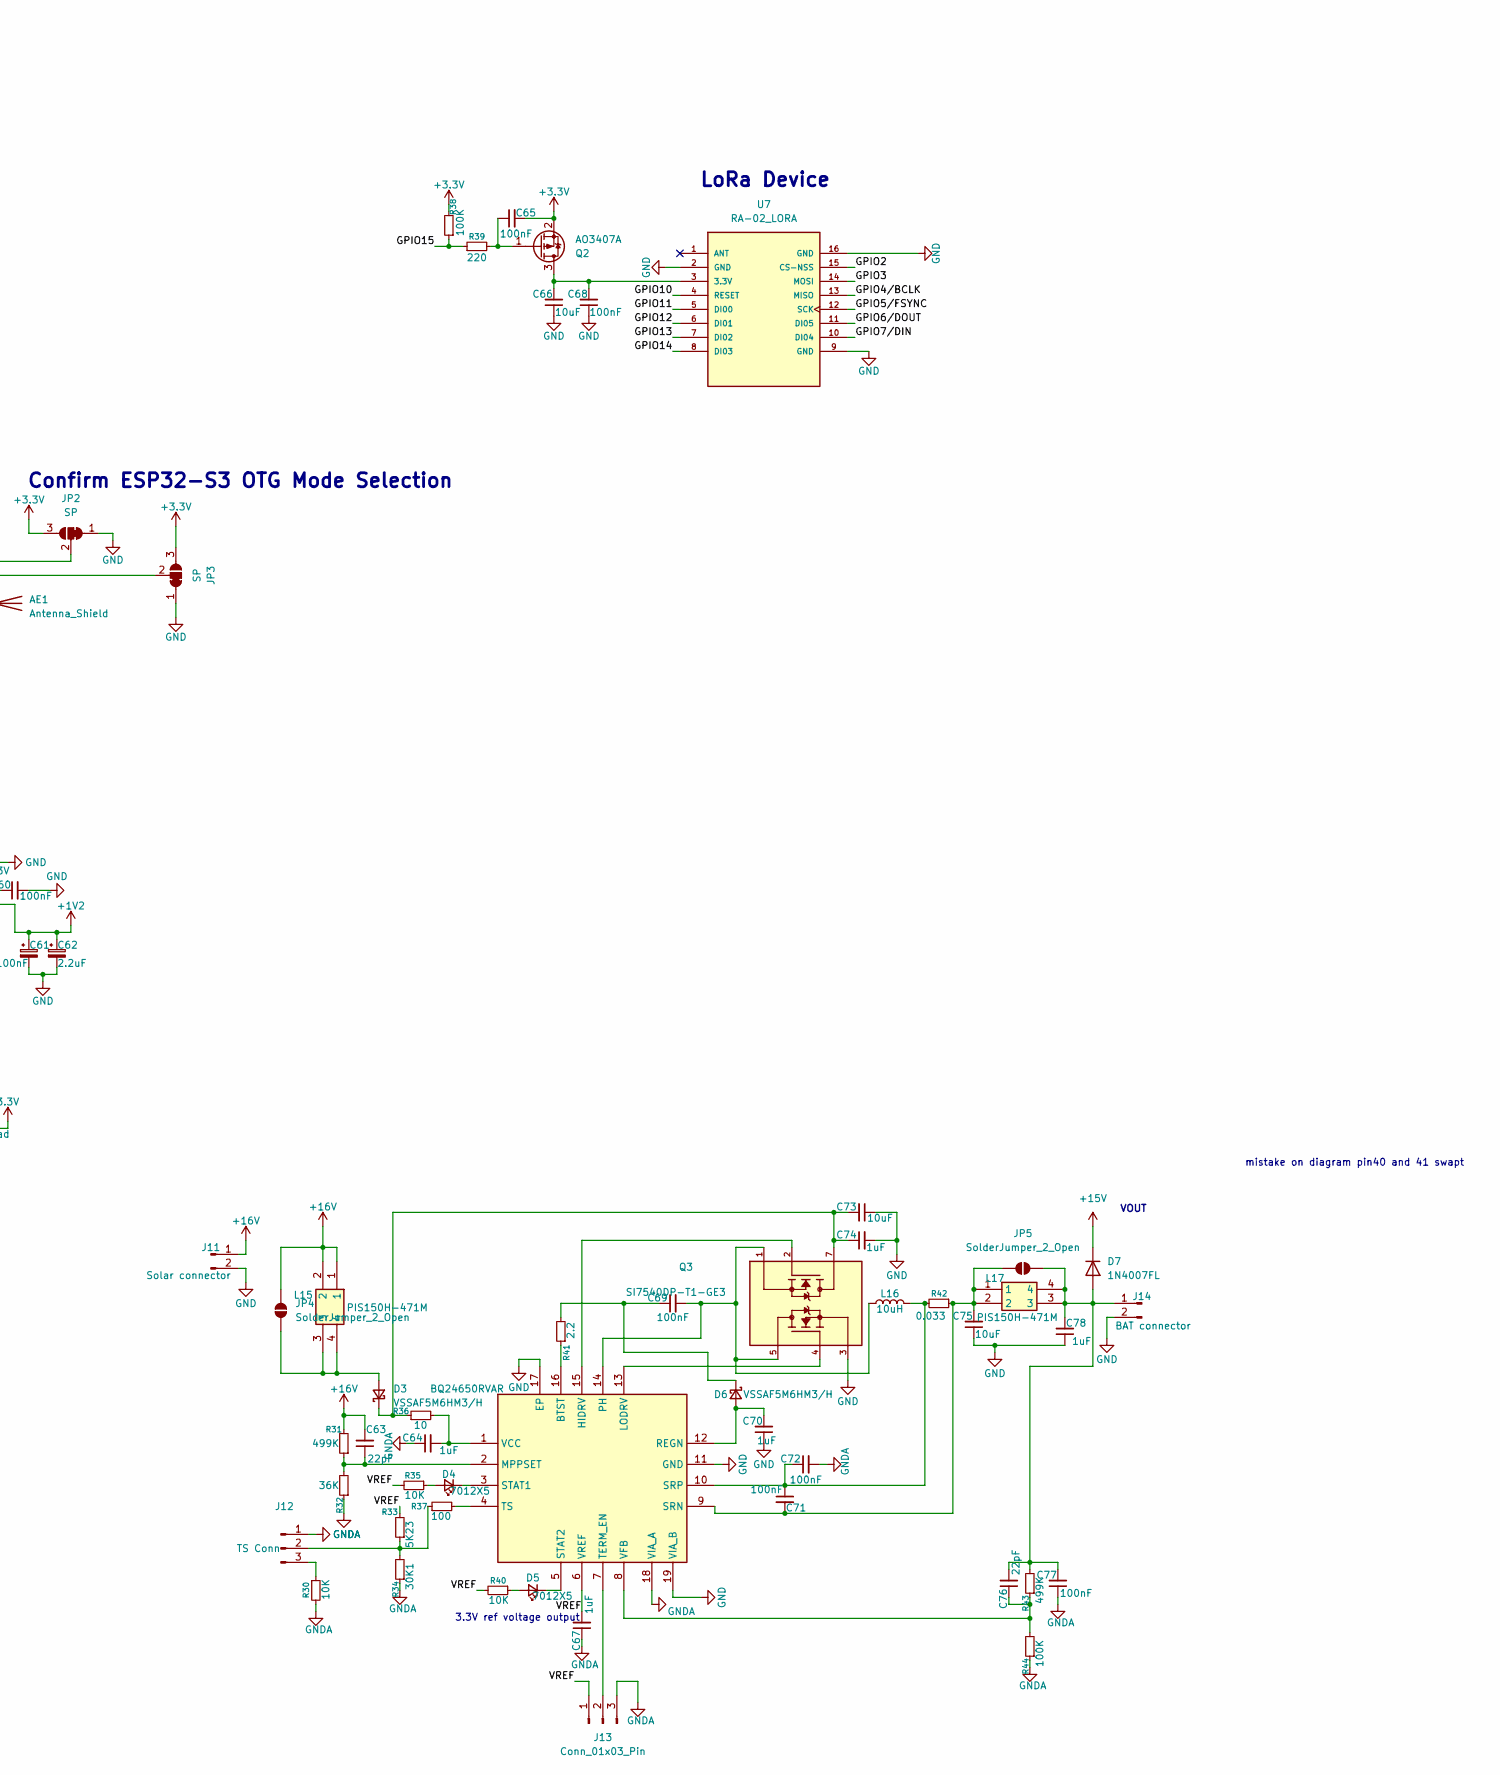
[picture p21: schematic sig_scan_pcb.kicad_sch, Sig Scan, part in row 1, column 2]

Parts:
AE1: Antenna_Shield; Texas_SWRA117D_2.4GHz_Left
C1, C18, C24, C40, C43, C47, C64, C67, C70, C74, C78: 1uF; C_0805_2012Metric
C2, C5, C9, C10, C12, C20, C25, C26, C31, C32, C35, C36, C37, C38, C39, C44, C45, C46, C48, C49, C51, C55, C56, C57, C60, C61, C65, C68, C69, C71, C72, C77: 100nF; C_0805_2012Metric
C3, C41, C52: 10nF; C_0805_2012Metric
C4: 330pF; C_0805_2012Metric
C6: 6n8F; C_0805_2012Metric
C7, C8, C34, C42, C50, C59, C66, C73, C75: 10uF; C_0805_2012Metric
C11, C15: 22uF; C_0805_2012Metric
C13, C17: DNP; C_0805_2012Metric
C14, C22: 132nF; C_0805_2012Metric
C16: 47uF; C_1206_3216Metric
C19: 212nF; C_0805_2012Metric
C21: 27pF; C_0805_2012Metric
C23, C27, C28: 10pF; C_0805_2012Metric
C29, C30: 39pF; C_0805_2012Metric
C33, C62: 2.2uF; C_0805_2012Metric
C53, C54, C58: 1.5pF; C_0805_2012Metric
C63, C76: 22pF; C_0805_2012Metric
D1, D2, D7: 1N4007FL; D_SOD-123
D3, D6: VSSAF5M6HM3/H; D_SMA
D4, D5: 7012X5; LED_0805_2012Metric
FB1, FB2: Bead; C_0805_2012Metric
IC1: AZ1117H-3.3TRE1; SOT230P700X180-4N; Mouser Part Number 621-AZ1117H-3.3TRE1
IC2: BQ24650RVAR; QFN50P350X350X100-17N-D; Mouser Part Number 595-BQ24650RVAR
J1: CON-SMA-EDGE-S; RFSOLUTIONS_CON-SMA-EDGE-S; PARTREV 1
J2: 12V Connector; CUI_TB007-508-02BE
J3: GPIO Connector; PinHeader_2x15_P2.54mm_Vertical
J4: UJ20-C-H-G-SMT-P16-TR; USB_C_Receptacle_G-Switch_GT-USB-7010ASV
J5: USB Switch; PinHeader_1x03_P2.54mm_Vertical
J6, J9: LED Connector; PinHeader_1x02_P2.54mm_Vertical
J7: CLK TP; PinHeader_1x01_P2.54mm_Vertical
J8: Conn; PinHeader_1x04_P2.54mm_Vertical
J10: PROG; PinHeader_1x04_P2.54mm_Vertical
J11: Solar connector; CUI_TB007-508-02BE
J12: TS Conn; PinHeader_1x03_P2.54mm_Vertical
J13: Conn_01x03_Pin; SolderJumper-3_P1.3mm_Bridged12_RoundedPad1.0x1.5mm
J14: BAT connector; CUI_TB007-508-02BE
JP1, JP4, JP5: SolderJumper_2_Open; SolderJumper-2_P1.3mm_Open_RoundedPad1.0x1.5mm
JP2, JP3: SP; SolderJumper-3_P1.3mm_Bridged12_RoundedPad1.0x1.5mm
L1: 100nH; L_0805_2012Metric
L2: 8n2H; L_0805_2012Metric
L3, L4: 150nH; L_0805_2012Metric
L5, L9: 118.1nH; L_0603_1608Metric
L6, L8: 478nH; L_0603_1608Metric
L7: 470uH; SRR12604R7Y
L10: 24nH; L_0805_2012Metric
L11: 10uH; L_0805_2012Metric
L12: 2nH; L_0603_1608Metric
L13, L14: 2.7nH; L_0805_2012Metric
L15, L17: PIS150H-471M; PIS150H471M; Mouser Part Number 871-PIS150H-471M
L16: 10uH; IND_IHLP_2525_CZ_VIS
Q1, Q2: AO3407A; SOT-23
Q3: SI7540DP-T1-GE3; TRANS_SI7540DP-T1-GE3; PARTREV 16MAY13
R1: 1K8; R_0805_2012Metric
R2, R15, R16, R22, R28, R30, R35, R40: 10K; R_0805_2012Metric
R3, R6: 5K1; R_0805_2012Metric
R4, R5, R24: 0 Ohm; R_0805_2012Metric
R7, R8, R9, R10: 22; R_0805_2012Metric
R11: 1K; R_0805_2012Metric
R12, R38, R44: 100K; R_0805_2012Metric
R13, R14, R26, R39: 220; R_0805_2012Metric
R17, R19, R20, R21, R27, R29: 4K7; R_0805_2012Metric
R18, R37: 100; R_0805_2012Metric
R23: 6K8; R_0805_2012Metric
R25: 499; R_0805_2012Metric
R31, R43: 499K; R_0805_2012Metric
R32: 36K; R_0805_2012Metric
R33: 5K23; R_0805_2012Metric
R34: 30K1; R_0805_2012Metric
R36: 10; R_0805_2012Metric
R41: 2.2; R_0805_2012Metric
R42: 0.033; R_1206_3216Metric
SW1: BOOT; SW_Tactile_SPST_NO_Straight_CK_PTS636Sx25SMTRLFS
SW2: RESET; SW_Tactile_SPST_NO_Straight_CK_PTS636Sx25SMTRLFS
T1: TCM1-382WX+; TCM1382WX; Mouser Part Number 139-TCM1-382WX
U1: BAV99-7-F; SOT-23_DIO
U2: AZ1117H-5.0TRE1; SOT230P700X180-4N; Mouser Part Number 621-AZ1117H-5.0TRE1
U3: R820T; QFN50P400X400X90-25N; PARTREV 1.2
U4: ESP32-S3FN8; QFN-56-1EP_7x7mm_P0.4mm_EP4x4mm
U5: RTL2832U; QFN40P600X600X100-49N; PARTREV 1.4
U6: M24C02-WMN; SOIC-8_3.9x4.9mm_P1.27mm
U7: RA-02_LORA; MODULE_RA-02_LORA; PARTREV 2018/03/02
Y1: 28.8MHz; ATX11F32000MHZF05T; Mouser Part Number 815-ATX11F32000MF05T
Y2: 40MHz; ABM810000MHZ12D2W

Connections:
3.3V: C2.1, C3.1, C10.1, C12.1, C25.2, C36.1, C50.1, C51.1, C52.1, C60.1, FB2.2, J8.1, Q1.3 (D), R11.2, R17.1, R20.1, U3.2 (VCC), U3.11 (VCC), U3.18 (VCC), U3.23 (VCC), U5.14 (VDD3), U5.33 (VDD3), U5.43 (VDDA33), U6.8 (VCC), Y1.1 (OE), Y1.4 (VDD)
+1V2: C31.1, C34.1, C57.1, C61.1, C62.1, FB1.1, L11.1, R24.1, U5.12 (VDD1), U5.20 (VDD1), U5.28 (VDD1), U5.34 (VDD1), U5.42 (UVDDA), U5.44 (VDDA), U5.47 (VDDA)
+3.3V: C26.2, C40.2, C41.2, C42.2, C43.2, C44.2, C46.1, C49.1, C65.2, J3.1, J6.2, J10.4, JP2.3 (B), JP3.3 (B), L7.2, L12.1, Q1.2 (S), Q2.2 (S), R12.2, R15.2, R16.2, R19.2, R21.2, R38.2, U4.20 (VDD3P3_RTC), U4.46 (VDD3P3_CPU), U4.55 (VDDA), U4.56 (VDDA)
+5V: C15.2, J5.1, L1.2, U2.2 (OUTPUT), U2.4 (VOUT)
+15V: C7.2, C8.2, D1.1 (K), D2.1 (K), D7.1 (K), IC1.3 (INPUT), U2.3 (INPUT)
+16V: C63.2, J11.1, JP4.2 (B), L15.1, L15.2, R31.2
/CHIP_PU: C24.2, R16.1, SW2.2, U4.4 (CHIP_PU)
/GPIO0: C23.2, R15.1, SW1.2, U4.5 (GPIO0)
/GPIO1: J3.11, R12.1, R14.1, U4.6 (GPIO1)
/GPIO2: U4.7 (GPIO2), U7.15 (CS-NSS)
/GPIO3: J3.9, U4.8 (GPIO3), U7.14 (MOSI)
/GPIO4/BCLK: J3.10, U4.9 (GPIO4), U7.13 (MISO)
/GPIO5/FSYNC: J3.7, U4.10 (GPIO5), U7.12 (SCK)
/GPIO6/DOUT: J3.8, U4.11 (GPIO6), U7.11 (DI05)
/GPIO7/DIN: J3.5, U4.12 (GPIO7), U7.10 (DI04)
/GPIO10: J3.21, U4.15 (GPIO10), U7.4 (RESET)
/GPIO11: J3.15, U4.16 (GPIO11), U7.5 (DI00)
/GPIO12: J3.13, U4.17 (GPIO12), U7.6 (DI01)
/GPIO13: J3.18, U4.18 (GPIO13), U7.7 (DI02)
/GPIO14: J3.17, U4.19 (GPIO14), U7.8 (DI03)
/GPIO15: J3.22, R38.1, R39.1, U4.21 (XTAL_32K_P)
/GPIO16: J3.19, U4.22 (XTAL_32K_N)
/GPIO17: J3.20, U4.23 (GPIO17)
/GPIO21: J3.23, U4.27 (GPIO21)
/GPIO38: J3.26, U4.43 (GPIO38)
/GPIO39/MTCK: J3.28, U4.44 (MTCK)
/GPIO40/MTDO: J3.30, U4.45 (MTDO)
/GPIO41/MTDI: J3.29, U4.47 (MTDI)
/GPIO42/MTMS: J3.27, U4.48 (MTMS)
/GPIO47: J3.25, U4.37 (SPICLK_P)
/GPIO48: J3.24, J9.2, U4.36 (SPICLK_N)
/SCL: J3.6, R19.1, U4.14 (GPIO9), U5.18 (I2C_SCL), U6.6 (SCL)
/SDA: J3.3, R21.1, U4.13 (GPIO8), U5.19 (I2C_SDA), U6.5 (SDA)
/USBD+: C13.1, J3.14, R5.2, U4.26 (GPIO20/USB_D+), U5.40 (USB_D+_(HSDP))
/USBD-: C17.1, J3.16, R4.2, U4.25 (GPIO19/USB_D-), U5.41 (USB_D−_(HSDM))
/VBUS: J4.A4 (VBUS), J4.A9 (VBUS), J4.B4 (VBUS), J4.B9 (VBUS), J5.2, R22.2
/VREF: C67.2, IC2.6 (VREF), J13.1, R33.2, R35.2, R40.2
GND: AE1.2 (Shield), C2.2, C3.2, C4.1, C5.1, C6.1, C7.1, C8.1, C9.2, C10.2, C11.1, C12.2, C13.2, C14.2, C15.1, C16.1, C17.2, C18.2, C19.2, C20.2, C22.2, C23.1, C24.1, C25.1, C27.1, C28.1, C29.1, C30.2, C31.2, C33.1, C34.2, C36.2, C38.1, C40.1, C41.1, C42.1, C43.1, C44.1, C45.1, C46.2, C47.2, C48.2, C49.2, C50.2, C51.2, C52.2, C53.2, C54.2, C55.2, C56.2, C57.2, C58.2, C59.2, C60.2, C61.2, C62.2, C66.1, C68.1, C70.1, C73.1, C74.2, C75.1, C78.1, IC1.1 (GND), IC2.11 (GND), IC2.17 (EP), IC2.19 (VIA_B), J1.G1, J1.G2, J1.G3, J1.G4, J2.2, J3.2, J4.A1 (GND), J4.A12 (GND), J4.B1 (GND), J4.B12 (GND), J4.S1 (SHIELD), J8.4, J10.1, J11.2, J14.2, JP2.1 (A), JP3.1 (A), Q3.3, R3.2, R6.2, R13.2, R23.1, R26.2, R28.2, SW1.1, SW2.1, T1.1 (GND_1), T1.2 (GND_2), U1.1 (EPAD), U1.2 (EPAD), U2.1 (ADJ/GND), U3.16 (GND), U3.25 (GND), U4.57 (GND), U5.3 (GNDA), U5.8 (GNDPLL), U5.39 (SEGND), U5.45 (GNDA), U5.49 (GND), U6.1 (E0), U6.2 (E1), U6.3 (E2), U6.4 (VSS), U6.7 (~WC), U7.2 (GND), U7.9 (GND), U7.16 (GND), Y1.2 (GND), Y2.2, Y2.4
GNDA: C64.1, C67.1, C72.2, C77.1, IC2.18 (VIA_A), J12.1, J13.3, R30.2, R32.1, R34.1, R44.1
unnamed: AE1.1 (A), C54.1, L13.2, L14.1
unnamed: C1.2, L2.1, U1.3 (EPAD)
unnamed: C6.2, R1.1
unnamed: C14.1, L5.2, L6.1
unnamed: C19.1, L6.2, L8.1
unnamed: C21.2, R18.1
unnamed: C22.1, L8.2, L9.1
unnamed: C27.2, L10.1, Y2.1
unnamed: C32.1, R8.2
unnamed: C35.1, R9.2
unnamed: C45.2, L12.2, U4.2 (VDD3P3), U4.3 (VDD3P3)
unnamed: C56.1, C59.1, FB2.1, U5.25 (SW_VDD3), U5.26 (SW_VDD3)
unnamed: C58.1, L14.2
unnamed: D1.2 (A), J2.1
unnamed: D2.2 (A), J5.3
unnamed: D3.2 (A), JP4.1 (A), L15.3, L15.4
unnamed: C73.2, C74.1, D3.1 (K), Q3.7, Q3.8, Q3.9, R36.1
unnamed: D4.2 (A), R35.1
unnamed: D4.1 (K), IC2.3 (STAT1)
unnamed: D5.2 (A), R40.1
unnamed: D5.1 (K), IC2.5 (STAT2)
unnamed: C70.2, D6.2 (A), IC2.12 (REGN)
unnamed: C69.1, D6.1 (K), R41.2
unnamed: C76.2, C77.2, C78.2, D7.2 (A), J14.1, JP5.1 (A), L17.3, L17.4, R43.2
unnamed: C11.2, C16.2, IC1.2 (OUTPUT), IC1.4 (VOUT), L7.1
unnamed: IC2.16 (BTST), R41.1
unnamed: IC2.15 (HIDRV), Q3.2
unnamed: IC2.13 (LODRV), Q3.4
unnamed: C63.1, IC2.2 (MPPSET), R31.1, R32.2
unnamed: C69.2, IC2.14 (PH), L16.1, Q3.1, Q3.5, Q3.6, Q3.10
unnamed: C71.2, C75.2, IC2.9 (SRN), JP5.2 (B), L17.1, L17.2, R42.1
unnamed: C71.1, C72.1, IC2.10 (SRP), L16.2, R42.2
unnamed: IC2.7 (TERM_EN), J13.2
unnamed: IC2.4 (TS), R37.2
unnamed: C64.2, IC2.1 (VCC), R36.2
unnamed: C76.1, IC2.8 (VFB), R43.1, R44.2
unnamed: J4.A5 (CC1), R3.1
unnamed: J4.B5 (CC2), R6.1
unnamed: J4.A6 (D+), J4.B6 (D+), R5.1
unnamed: J4.A7 (D-), J4.B7 (D-), R4.1
unnamed: J6.1, R13.1
unnamed: J7.1, U5.9 (TP_CKO)
unnamed: C37.1, J8.2, T1.5 (SECONDARY_DOT)
unnamed: C39.1, J8.3, T1.4 (SECONDARY)
unnamed: J9.1, R26.1
unnamed: J10.2, U4.50 (U0RXD)
unnamed: J10.3, R25.2
unnamed: J12.2, R33.1, R34.2, R37.1
unnamed: J12.3, R30.1
unnamed: C1.1, J1.1, JP1.1 (A)
unnamed: JP1.2 (B), L1.1
unnamed: JP2.2 (C), R27.1
unnamed: JP3.2 (C), R29.1
unnamed: C26.1, Q1.1 (G), R14.2
unnamed: C66.2, C68.2, Q2.3 (D), U7.3 (3.3V)
unnamed: C65.1, Q2.1 (G), R39.2
unnamed: L9.2, T1.3 (PRIMARY_DOT)
unnamed: C21.1, U3.10 (CLK_OUT)
unnamed: C4.2, R1.2, U3.15 (CP)
unnamed: C18.1, U3.4 (DET1)
unnamed: C20.1, U3.5 (DET2)
unnamed: C9.1, R2.1, U3.14 (IF_AGC)
unnamed: R9.1, U3.12 (IF_N)
unnamed: R8.1, U3.13 (IF_P)
unnamed: L5.1, U3.3 (LT)
unnamed: L2.2, U3.24 (RF_IN)
unnamed: R10.1, U3.6 (SCL)
unnamed: R7.1, U3.7 (SDA)
unnamed: L4.2, U3.21 (TF1N)
unnamed: L3.2, U3.22 (TF1P)
unnamed: L4.1, U3.19 (TF2N)
unnamed: L3.1, U3.20 (TF2P)
unnamed: C5.2, U3.17 (VDD_PLL)
unnamed: U3.8 (XTAL_I), Y1.3 (OUT)
unnamed: R22.1, R23.2, U4.24 (GPIO18)
unnamed: R27.2, U4.51 (GPIO45)
unnamed: R29.2, U4.52 (GPIO46)
unnamed: C53.1, L13.1, U4.1 (LNA_IN)
unnamed: R25.1, U4.49 (U0TXD)
unnamed: C47.1, C48.1, U4.29 (VDD_SPI)
unnamed: C28.2, U4.53 (XTAL_N), Y2.3
unnamed: L10.2, U4.54 (XTAL_P)
unnamed: R2.2, R11.1, U5.13 (AGC_IF)
unnamed: R24.2, U5.23 (FB)
unnamed: C29.2, R10.2, R17.2, U5.16 (I2C_SCLT)
unnamed: C30.1, R7.2, R20.2, U5.17 (I2C_SDAT)
unnamed: R28.1, U5.48 (R12K)
unnamed: L11.2, U5.24 (REG_OUT)
unnamed: C55.1, U5.46 (VCMI)
unnamed: C33.2, C38.2, FB1.2, U5.7 (VDDPLL)
unnamed: C35.2, U5.2 (VIN)
unnamed: C32.2, U5.1 (VIP)
unnamed: C37.2, U5.5 (VQN)
unnamed: C39.2, U5.4 (VQP)
unnamed: R18.2, U5.11 (XI)

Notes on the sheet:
LoRa Device
Bring out Q+ Q- to connector
VOUT
3.3V ref voltage output
Pin16 is PLL reference GND, please don't connect pin16 to E-PAD
mistake on diagram pin40 and 41 swapt
GND guard with more via
Confirm ESP32-S3 OTG Mode Selection

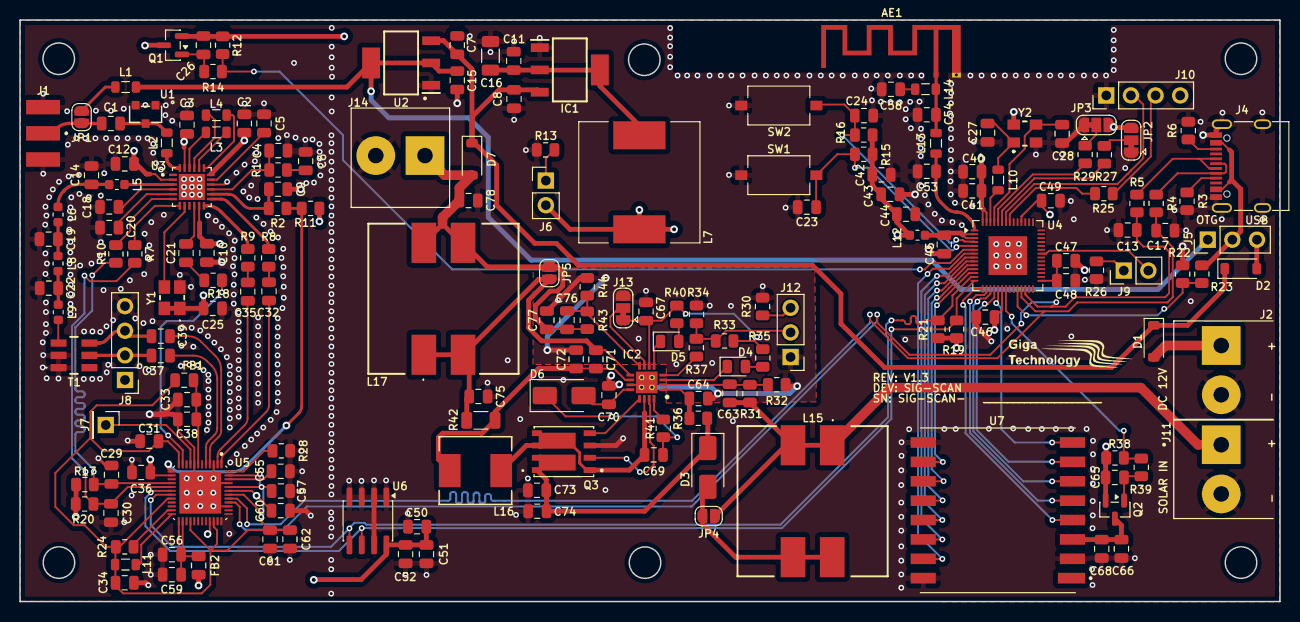
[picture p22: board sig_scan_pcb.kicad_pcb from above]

Board: 4 copper layers, 130.0 x 60.0 mm, 184 parts (0 on the bottom side), 125 nets.

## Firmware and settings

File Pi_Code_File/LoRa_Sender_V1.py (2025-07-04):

import numpy as np
import time
import threading
from flask import Flask, request, render_template_string
from rtlsdr import RtlSdr
import sx126x
from datetime import datetime
import json
import os

# === CONFIG FILE PATH ===
CONFIG_FILE = os.path.join(os.path.dirname(__file__), "config.json")

# LoRa setup
lora = sx126x.sx126x(
    serial_num="/dev/ttyS0",
    freq=868,
    addr=0,
    power=22,
    rssi=True,
    air_speed=2400,
    relay=False
)

FREQUENCY_BANDS = {
    "2G_LOW": [(900e6, 950e6)],
    "2G_HIGH": [(1800e6, 1900e6)],
    "3G": [(1920e6, 2170e6)],
    "4G": [(2300e6, 2700e6)],
    "5G": [(3300e6, 3800e6)]
}

DEFAULT_THRESHOLDS = {
    "2G_LOW": -8,
    "2G_HIGH": -8,
    "3G": -10,
    "4G": -10,
    "5G": -10
}

power_history = {band: [] for band in FREQUENCY_BANDS}
manual_thresholds = DEFAULT_THRESHOLDS.copy()
auto_margins = {band: 2.0 for band in FREQUENCY_BANDS}
trigger_mode = {'mode': 'auto'}

scan_stats = {
    band: {"avg": None, "max": None, "min": None}
    for band in FREQUENCY_BANDS
}

# === CONFIG LOAD/SAVE ===
def save_config():
    config = {
        "trigger_mode": trigger_mode['mode'],
        "manual_thresholds": manual_thresholds,
        "auto_margins": auto_margins
    }
    with open(CONFIG_FILE, "w") as f:
        json.dump(config, f, indent=2)
    print("[CONFIG] Saved to config.json")

def load_config():
    try:
        with open(CONFIG_FILE, "r") as f:
            config = json.load(f)
            trigger_mode['mode'] = config.get("trigger_mode", "auto")
            manual_thresholds.update(config.get("manual_thresholds", {}))
            auto_margins.update(config.get("auto_margins", {}))
        print("[CONFIG] Loaded from config.json")
    except FileNotFoundError:
        print("[CONFIG] config.json not found, using defaults")

# === Load configuration on startup ===
load_config()

sdr = RtlSdr()
sdr.sample_rate = 2.4e6
sdr.gain = 'auto'

app = Flask(__name__)

HTML_TEMPLATE = """<!doctype html>
<html lang="en">
<head>
  <meta charset="UTF-8">
  <meta http-equiv="refresh" content="10">
  <meta name="viewport" content="width=device-width, initial-scale=1.0">
  <title>Trigger Mode Control</title>
  <style>
    body { font-family: sans-serif; background-color: #121212; color: #f1f1f1; margin: 0; padding: 1rem; }
    h2, h3 { text-align: center; }
    form { max-width: 400px; margin: 1rem auto; background: #1e1e1e; padding: 1rem; border-radius: 8px; box-shadow: 0 0 10px rgba(0,0,0,0.5); }
    label { display: block; margin-top: 1rem; }
    input[type="text"] { width: 100%; padding: 0.5rem; border: 1px solid #555; border-radius: 5px; background-color: #2c2c2c; color: #fff; }
    button { width: 100%; padding: 0.75rem; margin-top: 1rem; background-color: #4CAF50; color: white; border: none; border-radius: 5px; font-size: 1rem; cursor: pointer; }
    button:hover { background-color: #45a049; }
    table { margin: 1rem auto; border-collapse: collapse; width: 80%; }
    th, td { border: 1px solid #444; padding: 0.5rem; text-align: center; }
    th { background-color: #222; }
    .footer { text-align: center; font-size: 0.8rem; margin-top: 2rem; color: #888; }
  </style>
</head>
<body>
  <h2>Trigger Mode: {{ mode.upper() }}</h2>
  
  <form method="post" action="/toggle">
    <button type="submit">Switch to {{ 'Manual' if mode == 'auto' else 'Auto' }}</button>
  </form>

  {% if mode == 'manual' %}
  <form method="post" action="/set_thresholds">
    {% for band in bands %}
      <label>{{ band }} Manual Threshold (dB):</label>
      <input type="text" name="{{ band }}" value="{{ thresholds[band] }}">
    {% endfor %}
    <button type="submit">Update Manual Thresholds</button>
  </form>
  {% endif %}

  <form method="post" action="/set_margins">
    {% for band in bands %}
      <label>{{ band }} Auto Margin (dB):</label>
      <input type="text" name="{{ band }}" value="{{ margins[band] }}">
    {% endfor %}
    <button type="submit">Update Auto Margins</button>
  </form>

  <h3>Current Scan Statistics</h3>
  <table>
    <tr>
      <th>Band</th>
      <th>Avg dB</th>
      <th>Max dB</th>
      <th>Min dB</th>
    </tr>
    {% for band in bands %}
    <tr>
      <td>{{ band }}</td>
      <td>{{ stats[band]['avg'] if stats[band]['avg'] is not none else 'N/A' }}</td>
      <td>{{ stats[band]['max'] if stats[band]['max'] is not none else 'N/A' }}</td>
      <td>{{ stats[band]['min'] if stats[band]['min'] is not none else 'N/A' }}</td>
    </tr>
    {% endfor %}
  </table>

  <div class="footer">SDR Trigger Control Panel</div>
</body>
</html>
"""

@app.route("/", methods=["GET"])
def home():
    return render_template_string(
        HTML_TEMPLATE,
        mode=trigger_mode['mode'],
        bands=FREQUENCY_BANDS.keys(),
        thresholds=manual_thresholds,
        margins=auto_margins,
        stats=scan_stats
    )

@app.route("/toggle", methods=["POST"])
def toggle_mode():
    trigger_mode['mode'] = 'manual' if trigger_mode['mode'] == 'auto' else 'auto'
    save_config()
    return home()

@app.route("/set_thresholds", methods=["POST"])
def set_thresholds():
    for band in FREQUENCY_BANDS.keys():
        try:
            manual_thresholds[band] = float(request.form[band])
        except ValueError:
            pass
    save_config()
    return home()

@app.route("/set_margins", methods=["POST"])
def set_margins():
    for band in FREQUENCY_BANDS.keys():
        try:
            auto_margins[band] = float(request.form[band])
        except ValueError:
            pass
    save_config()
    return home()

def run_web_server():
    app.run(host='0.0.0.0', port=8080)

def scan_band(freq_range, label):
    start_freq, end_freq = freq_range
    step_size = 2e6
    detected = False
    powers = []

    for freq in np.arange(start_freq, end_freq, step_size):
        sdr.center_freq = freq
        samples = sdr.read_samples(256*1024)
        power = 10 * np.log10(np.mean(np.abs(samples)**2))
        powers.append(power)

        print(f"Scanning {label}: {freq/1e6:.2f} MHz — Power = {power:.2f} dB")

        if trigger_mode['mode'] == 'manual':
            threshold = manual_thresholds[label]
        else:
            avg_power = (sum(power_history[label]) / len(power_history[label])) if power_history[label] else DEFAULT_THRESHOLDS[label]
            threshold = avg_power + auto_margins[label]

        if power > threshold:
            alert_data = {
                "alert": {
                    "Band": "2G" if label.startswith("2G_") else label,
                    "Freq": f"{int(freq/1e6)}MHz",
                    "DBi": round(power, 2),
                    "Threshold": round(threshold, 2),
                    "timestamp": datetime.now().strftime("%Y-%m-%d %H:%M:%S")
                }
            }
            alert_message = json.dumps(alert_data).encode('utf-8')
            data = bytes([255, 255, 18, 255, 255, 12]) + alert_message
            lora.send(data)
            print(f"ALERT: {label} Strong Signal Detected {freq/1e6}MHz > {threshold:.2f}dB")
            detected = True

    power_history[label] = powers

    if powers:
        avg_dbi = round((sum(powers) / len(powers)) + auto_margins[label], 2)
        max_dbi = round(max(powers), 2)
        min_dbi = round(min(powers), 2)

        scan_stats[label]["avg"] = avg_dbi
        scan_stats[label]["max"] = max_dbi
        scan_stats[label]["min"] = min_dbi

        summary_data = {
            "scan_summary": {
                "Band": "2G" if label.startswith("2G_") else label,
                "avgDBi": avg_dbi,
                "maxDBi": max_dbi,
                "minDBi": min_dbi,
                "timestamp": datetime.now().strftime("%Y-%m-%d %H:%M:%S")
            }
        }
        summary_message = json.dumps(summary_data).encode('utf-8')
        data = bytes([255, 255, 18, 255, 255, 12]) + summary_message

        time.sleep(0.2)
        lora.send(data)
        print(f"SUMMARY: {label} — Avg: {avg_dbi:.2f} dB, Max: {max_dbi:.2f} dB, Min: {min_dbi:.2f} dB")
        time.sleep(1)

    return detected

def main_loop():
    print("Starting SDR + LoRa Alert System...")
    while True:
        for band, freq_ranges in FREQUENCY_BANDS.items():
            for freq_range in freq_ranges:
                scan_band(freq_range, band)
        time.sleep(5)

if __name__ == "__main__":
    try:
        web_thread = threading.Thread(target=run_web_server, daemon=True)
        web_thread.start()
        main_loop()
    except KeyboardInterrupt:
        print("Stopping...")
        sdr.close()

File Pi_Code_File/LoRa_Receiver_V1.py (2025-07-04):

import sys
import sx126x
import time
import json
import threading
from flask import Flask, jsonify, render_template
from collections import defaultdict
import paho.mqtt.client as mqtt

# MQTT Settings
MQTT_BROKER = "iot.giga.co.za"
MQTT_PORT = 1883
MQTT_USERNAME = "homeassistant"
MQTT_PASSWORD = "h0m3@ss1$tant"
MQTT_TOPIC = "sig_scan/alert"

app = Flask(__name__)
alert_log = []  # last 100 alerts
avg_dbi_per_band = defaultdict(lambda: -10)  # fallback

# LoRa
node = sx126x.sx126x(
    serial_num="/dev/ttyS0",
    freq=868,
    addr=65535,
    power=22,
    rssi=True,
    air_speed=2400,
    relay=False
)
LORA_PREFIX = b'\xff\xff\x0c'

@app.route('/')
def index():
    return render_template('index.html')

@app.route('/alerts')
def get_alerts():
    return jsonify(alert_log[::-1])

@app.route('/thresholds')
def get_thresholds():
    return jsonify(avg_dbi_per_band)

def extract_json_messages(data):
    messages = []
    parts = data.split(LORA_PREFIX)
    for part in parts[1:]:
        try:
            json_str = part.decode("utf-8", errors="ignore")
            start_idx = json_str.find("{")
            end_idx = json_str.rfind("}")
            if start_idx != -1 and end_idx != -1:
                clean_json = json_str[start_idx:end_idx + 1]
                obj = json.loads(clean_json)
                messages.append(obj)
        except Exception as e:
            print(f"[WARN] Failed to parse JSON: {e}")
    return messages

def receive_lora():
    while True:
        if node.ser.inWaiting() > 0:
            time.sleep(0.5)
            r_buff = node.ser.read(node.ser.inWaiting())
            messages = extract_json_messages(r_buff)
            for msg in messages:
                try:
                    if "alert" in msg:
                        alert = {
                            "alert": msg["alert"]["Band"],
                            "frequency": msg["alert"]["Freq"],
                            "trigger_level": msg["alert"]["DBi"],
                            "avgDBi": msg["alert"]["Threshold"],
                            "timestamp": msg["alert"]["timestamp"]
                        }
                        alert_log.append(alert)
                        if len(alert_log) > 100:
                            alert_log.pop(0)

                        print(f"\n[ALERT RECEIVED]")
                        print(json.dumps(alert, indent=4))
                        send_mqtt_alert(json.dumps(alert))

                    elif "scan_summary" in msg:
                        summary = msg["scan_summary"]
                        band = summary["Band"]
                        avg_dbi = summary["avgDBi"]
                        avg_dbi_per_band[band] = avg_dbi
                        print(f"[SUMMARY RECEIVED] {band} avgDBi={avg_dbi}")

                except Exception as e:
                    print(f"[ERROR] Failed to handle message: {e}")
                    print(f"Raw msg: {msg}")
        time.sleep(0.1)

def send_mqtt_alert(mqtt_data):
    mqtt_client = mqtt.Client()
    mqtt_client.username_pw_set(MQTT_USERNAME, MQTT_PASSWORD)
    mqtt_client.connect(MQTT_BROKER, MQTT_PORT, 60)
    mqtt_client.loop_start()
    mqtt_client.publish(MQTT_TOPIC, mqtt_data)
    mqtt_client.loop_stop()

# Threads
threading.Thread(target=receive_lora, daemon=True).start()
threading.Thread(target=lambda: app.run(host='0.0.0.0', port=5000), daemon=True).start()

print("LoRa receiver and web server started. Running indefinitely.")
while True:
    time.sleep(1)

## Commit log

2025-05-30 Adding files to restore USB to LoRa device
2025-08-27 adding the kicad project
    [sig_scan_pcb.kicad_pcb, sig_scan_pcb.kicad_sch]
2025-08-30 adding uncompleet rtl-sdr design
    [sig_scan_pcb.kicad_sch]
2025-10-10 almost compleet design needs psu
    [RA-02_LORA.step, sig_scan_pcb.kicad_sch]
2025-11-27 Updating PCB to final design and updating partlist
    [ATX-11-F-32.000MHZ-F05-T.SchLib, ATX-11-F-32.000MHZ-F05-T.stp, ATX11F32000MHZF05T.PcbLib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]
2025-12-01 Adding Gerber files
    [sig_scan_pcb-B_Cu.gbr, sig_scan_pcb-B_Mask.gbr, sig_scan_pcb-B_Paste.gbr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]
2025-12-01 Adding Gerber zip file
    [sig_scan_pcb-B_Cu.gbr, sig_scan_pcb-B_Mask.gbr, sig_scan_pcb-B_Paste.gbr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]
2025-12-05 Updating Gerber files with correct clearances
    [sig_scan_pcb-B_Cu.gbr, sig_scan_pcb-B_Mask.gbr, sig_scan_pcb-B_Paste.gbr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]
2025-12-05 3d view of PCB
2026-01-07 Updating ground planes for solar chip and updating Gerber files
    [Sig_Scan_Partlist.xlsx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]
2026-01-08 Adding fixed isolation to gerber files
    [sig_scan_pcb-B_Cu.gbr, sig_scan_pcb-B_Mask.gbr, sig_scan_pcb-B_Paste.gbr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]

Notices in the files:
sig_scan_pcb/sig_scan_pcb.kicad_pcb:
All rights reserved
